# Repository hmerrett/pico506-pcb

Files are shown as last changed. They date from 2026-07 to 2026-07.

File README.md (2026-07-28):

# Pico506 hardware — rev 1.0

A dedicated PCB for the Pico506 ST-506/MFM/RLL hard drive emulator: two-layer,
138 × 74 mm, all through-hole, with real card-edge tabs so it plugs into a
period ST-506 control/data cable pair the same way an ST-225 does.

**This repository is the board only.** The emulator itself — the RP2040 firmware,
the PIO signal generation, the SD card image format, and the explanation of how
any of it works — is Kuba Szczodrzyński's
[**kuba2k2/pico506**](https://github.com/kuba2k2/pico506). Read that first; this
board is useless without it. Kuba's write-up
[*Emulating a 1987 proprietary RLL hard drive*](https://kuba.szczodrzynski.pl/posts/toshiba-t1200/rll-hdd-emulator/)
is the long-form story of the project and the reference for the interface
behaviour this layout is built around.

This file covers the board: what to buy, how to strap it, and what to tell
the fab. See [Credits](#credits) for what is original here and what is not.

> **Status:** schematic and layout are complete and clean — ERC 0, DRC 0 at
> `--severity-all` (see [`erc.txt`](erc.txt), [`drc.txt`](drc.txt)).
> **It has not been fabricated or brought up yet.** Nothing here has been
> validated against real hardware; treat rev 1.0 as a first spin.

| Front | Back |
|---|---|
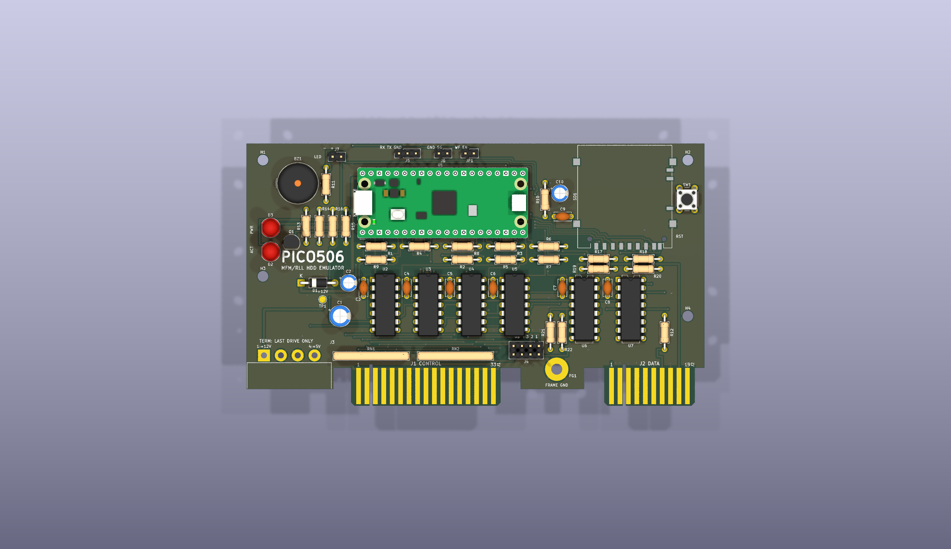
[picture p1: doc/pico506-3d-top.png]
front
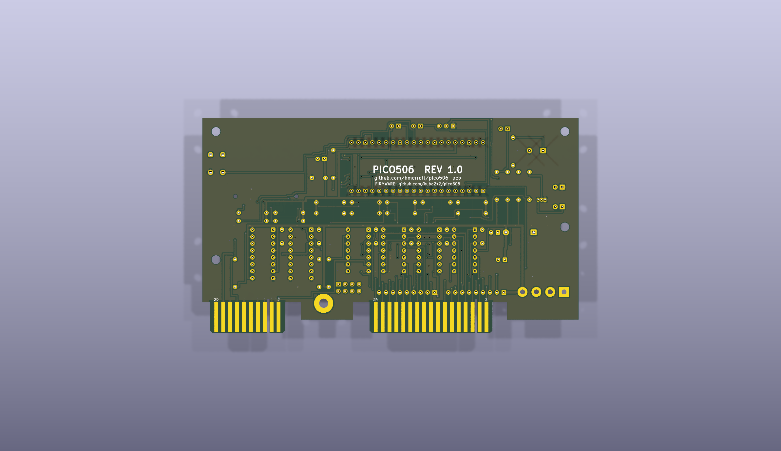
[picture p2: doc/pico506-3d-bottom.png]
back
|  |  |

Also in [`doc/`](doc/): an isometric render, front/back layer PDFs, gerbers +
Excellon (`pico506-gerbers.zip`), a CSV BOM and a placement file. The schematic
PDF is [`pico506-sch.pdf`](pico506-sch.pdf).

## Bill of materials

36 line items, 62 parts, nothing surface-mount and nothing exotic. Quantities
and designators below are generated from the schematic — the machine-readable
copy is [`doc/pico506-bom.csv`](doc/pico506-bom.csv).

### Semiconductors

| Ref | Qty | Value | Notes |
|---|---|---|---|
| U1 | 1 | Raspberry Pi Pico | Pico or Pico W, THT header or castellated. The footprint takes either. |
| U2, U3 | 2 | 74LS05 | Hex inverter, **open collector**. Not 7404 — the open-collector output is what lets the terminated 5 V bus idle high. |
| U4, U5 | 2 | 7438 | Quad NAND, **open collector**, buffered. Plain `7438` (or `74S38`) is preferred over `74LS38`: the LS part sinks 24 mA where the bus wants 40 mA to hold a 220/330-terminated line at a valid low. 74LS38 will usually work with one drive on a short cable; use 7438 if you want spec margin. |
| U6 | 1 | AM26LS31CN | Quad RS-422 differential **driver** (READ data out). |
| U7 | 1 | MC3486N | Quad RS-422 differential **receiver** (WRITE data in). **AM26LS32AC** is a drop-in alternative and is usually easier to find. |
| Q1 | 1 | 2N3904 | LED sink for the front-panel activity LED. Any small NPN. |
| D1 | 1 | 1N5817 | Schottky, feeds the Pico's VSYS from +5 V. A 1N5819 or SS14-class part is fine; don't substitute a plain 1N400x — the forward drop leaves too little VSYS headroom. |
| D2 | 1 | LED 5 mm amber | `ACT` — activity. |
| D3 | 1 | LED 5 mm green | `PWR` — power. |

### Passives

| Ref | Qty | Value | Notes |
|---|---|---|---|
| RN1 | 1 | 220 Ω SIP-9 | Terminator pull-up half. **Bourns 4609X-101-221** (bussed, 8 resistors, common pin 1). Fit in a 9-pin SIP socket — see [Termination](#termination). |
| RN2 | 1 | 330 Ω SIP-9 | Terminator pull-down half. **Bourns 4609X-101-331**. Also socketed. |
| R21 | 1 | 220 Ω | Fixed 220/330 divider on the *selected* drive-select line, after the J4 jumper — the way an ST-225 does it. Not removable. |
| R22 | 1 | 330 Ω | ” |
| R1–R9, R16 | 10 | 1 kΩ | R1–R9 pull the 74LS05 open-collector outputs up to +3V3 for the Pico. R16 is the PWR LED resistor. |
| R10, R14, R15 | 3 | 470 Ω | R10 is the WRITE FAULT input pull-up; R14/R15 are the ACT LED resistors (on-board and front-panel). |
| R11, R12 | 2 | 100 Ω | R11 buzzer series, R12 terminates the WRITE differential pair across U7's inputs. |
| R13 | 1 | 4.7 kΩ | Q1 base. |
| R17–R20 | 4 | 10 kΩ | SD card SPI pull-ups. |
| C1 | 1 | 100 µF 16 V | Bulk on +5 V. Radial, 6.3 mm body, 2.5 mm pitch. |
| C2 | 1 | 22 µF 16 V | Bulk on VSYS. Radial, 5 mm body. |
| C3–C9 | 7 | 100 nF | Ceramic disc, 5 mm pitch. One per logic IC (C3–C8) plus one for the SD socket (C9). |
| C10 | 1 | 10 µF 16 V | +3V3 bulk next to the SD socket. |

All resistors are 1/4 W axial on a 10.16 mm (0.4 in) footprint — the classic
DIN0207 body with the leads bent out, so they lie flat.

### Connectors and mechanical

| Ref | Qty | Part | Notes |
|---|---|---|---|
| J1 | — | ST-506 control, 34-pin card edge | Etched into the board. Mates a 3M 3463 / AMP 88373-3 style IDC card-edge socket. |
| J2 | — | ST-506 data, 20-pin card edge | Etched into the board. Mates 3M 3461 / AMP 88373-6. |
| J3 | 1 | **AMP/TE 350211-1** 4-pos MATE-N-LOK | Cable side is **AMP 1-480424-0** with 350550-series pins. This is the standard 4-pin drive power connector. The footprint expects the vertical header with its legs formed 90° for rear entry — exactly what Seagate did — or use a right-angle MATE-N-LOK equivalent. |
| FG1 | 1 | **AMP 61761-2** faston tab | Frame ground, 0.187 in tab, 3.3 mm hole. Or just bolt a ring lug through it. |
| SD1 | 1 | **Hirose DM1AA-SF-PEJ(82)** | Full-size push-push SD socket. The card ejects over the board's front edge. |
| SW1 | 1 | 6 mm tactile switch, 4.3 mm | `RST` — pulls the Pico's RUN low. |
| J4 | 1 | 2×4 pin header, 2.54 mm | Drive select. See [Straps](#straps-and-jumpers). |
| J5 | 1 | 1×3 pin header | UART console: GND / TX / RX. |
| J6 | 1 | 1×2 pin header | `SERVO GATE` — 3.3 V logic, JVC RLL drives only. |
| J7 | 1 | 1×2 pin header | Front-panel activity LED: pin 1 anode, pin 2 cathode. |
| JP1 | 1 | 1×2 pin header | `WF EN` — WRITE FAULT enable. |
| TP1 | 1 | test pad | +12 V, so you can confirm the rail without probing the connector. |
| H1–H4 | 4 | M3 | 3.2 mm mounting holes. |
| — | 6 | DIP socket | 4 × DIP-14, 2 × DIP-16. Optional but recommended. |
| — | 2 | SIP-9 socket | For RN1/RN2, so the terminator can come out. **Not optional** if this drive might sit mid-chain. |

## Straps and jumpers

### J4 — drive select

The silkscreen reads `DS 4 3 2 1` left to right (west to east). Each column is
one J1 drive-select line on its odd pin and the shared `DS_SEL_N` node on its
even pin; fitting a shunt across one column selects that drive address.
**Fit exactly one shunt.**

| Column | J1 pin | Selects |
|---|---|---|
| `1` (east) | 26 | DS1 |
| `2` | 28 | DS2 |
| `3` | 30 | DS3 |
| `4` (west) | 32 | DS4 |

Which one you want depends on your controller's cable. With a straight-through
control cable, the first drive is DS1. With an **IBM-style twisted control
cable** the twist reassigns the select lines between the two drive connectors,
and the drive on the end (twisted) connector wants **DS2** — that is the
intended default for this board. Check your controller's manual: this is the
single most common reason an otherwise-working drive is not detected.

Downstream of the shunt, `DS_SEL_N` carries its own fixed 220/330 divider
(R21/R22), matching ST-225 practice — that termination stays fitted regardless
of chain position.

### Other headers

| Header | Fitted | Effect |
|---|---|---|
| JP1 `WF EN` | open (default) | WRITE FAULT is not driven; the line idles inactive via R10. |
| JP1 `WF EN` | closed | Firmware drives WRITE FAULT from GP22. Only close this if your firmware build actually asserts it. |
| J6 `SERVO GATE` | — | 3.3 V SERVO GATE for JVC JD-3824-class RLL drives. Leave unconnected for ordinary MFM. |
| J7 `FRONT LED` | — | Parallels the on-board ACT LED to a panel LED. Pin 1 is the anode. |
| J5 `UART` | — | Console at GND/TX/RX. 3.3 V logic — do not connect a 5 V TTL adapter. |

## Termination

ST-506 is a daisy chain, and the spec puts a 220 Ω/330 Ω divider on every
control input — but **only on the drive at the far end of the cable.** Every
other drive on the chain must have its terminator removed, or the lines are
loaded several times over and nothing reads reliably.

That is what RN1 (220 Ω) and RN2 (330 Ω) are, and it is why they belong in
sockets:

- **Last drive on the control cable** (or the only drive): RN1 and RN2 fitted.
- **Any other position:** pull both packs out.

The silkscreen says `TERM: LAST DRIVE ONLY` next to them as a reminder. The
data cable (J2) is point-to-point and needs no such choice — the WRITE pair's
terminator (R12) is soldered down.

## Connectors and keying

Both card-edge tabs stand 5 mm proud of the main outline, are 1.6 mm thick, and
carry a **0.914 mm key slot routed 12.5 mm in from the tab tip, between pins 4
and 6** — the standard ST-506 keying, so a connector cannot be seated
backwards. Odd pins are on the front (F.Cu) face, even pins on the back, at
2.54 mm pitch; fingers are 1.40 mm wide and 11.43 mm long with the copper
pulled back 0.45 mm from the routed tip.

### Relief cut-outs

The fingers are 11.43 mm long but the tab only stands 5 mm proud, so the board
is cut away **beside** each tab as well — otherwise the mating socket's shell
hits the main board edge after 5 mm with two thirds of the finger length still
unengaged. Each relief runs inboard to y = 67.57 mm, level with the finger
tops, giving a free-standing tongue exactly as long as the gold:

| Relief | Width | Note |
|---|---|---|
| J1 west | **5.34 mm** | Limited by the J3 power housing 0.6 mm further west, not by choice — see below. |
| J1 east | 6.00 mm | |
| J2 west | 6.00 mm | |
| J2 east | 2.90 mm | The board simply ends here; the whole south-east corner is removed, so there is nothing east of the J2 tab to foul. |

The overall envelope is unchanged — 138 × 74 mm plus the 5 mm tabs — so this
costs nothing mechanically.

> **Check this against your actual sockets.** The J1 relief can only be
> 5.34 mm wide on its west side, because the J3 power connector housing (a full
> 1.00 in wide, its east face at x = 25.62 mm) is immediately beyond it. If
> your J1 socket needs more than that, the obstruction is the *power connector
> body*, not the board, and the fix is to shift J3 east — which moves it off the
> measured ST-225 position. `TAB_RELIEF_W` in
> [`tools/layout.py`](tools/layout.py) is the single knob for relief width.

Extending the tabs further instead of notching would also work and is a
one-constant change (`TAB_PROTRUDE`), but it moves every finger pad south,
invalidates all the hand-routed finger escapes, and grows the board's depth
past the drive's rear plane.

Lateral positions follow the measured ST-225 arrangement so ordinary cable
dressing just works. Measured from the board's west edge:

| Tab | Centre | Width | Pins |
|---|---|---|---|
| J1 control | 54.10 mm | 45.09 mm | 34 |
| J2 data | 121.45 mm | 27.30 mm | 20 |

J1 uses the ST-506/412 control pinout (even pins signal, odd pins ground); J2
uses the ST-412 data pinout, with the two differential pairs on 13/14 (WRITE)
and 17/18 (READ). Both are enumerated in
[`tools/netlist.py`](tools/netlist.py), which is the single source of truth for
the whole design.

J3 power is the usual 4-pin order: **pin 1 = +12 V**, pins 2 and 3 ground,
**pin 4 = +5 V**, marked on the silkscreen. +12 V is not used by the emulator —
it is brought to TP1 only so you can verify the supply.

## Mechanical

Everything below is from [`tools/layout.py`](tools/layout.py); the origin is the
board's north-west corner viewed from the component side.

- **Main outline:** 138.0 × 74.0 mm, 1.6 mm FR4. The rear (south) edge is the
  drive's rear plane; the two card-edge tabs protrude 5 mm past it for cable
  access, with 1 mm 45° corner cuts at the tab tips. The board is notched
  beside each tab so the sockets can seat — see
  [Relief cut-outs](#relief-cut-outs). The south-east corner is cut away
  entirely as part of that.
- **Mounting holes** (3.2 mm, M3): H1 (5, 5), H2 (133, 5), H3 (5, 40),
  H4 (133, 52).
- **Frame ground** faston FG1 sits between the two tabs, 6 mm in from the rear
  edge at x = 93.5.
- **SD card** ejects over the *front* (north) edge — leave that edge clear in
  any enclosure.
- **USB** and the `RST` button are the other two things you will want access
  to: USB is at the Pico's west end, `RST` at the east edge.

If you are building an enclosure or a bay adapter: this board is not a
mechanical drop-in for a 3.5 in or 5.25 in drive. It reproduces the *electrical
and connector* geometry of an ST-225 rear face, not its chassis. On a real
drive the card-edge mid-plane sits roughly 4.8 mm above the bay floor; if you
want the cables to land where a drive's would, that is the dimension to match,
and SFF-8501 gives the bay hole pattern to mount against. The four holes here
are a generic rectangle, not the SFF pattern — pick them up with standoffs.

## Fab notes

Two layers, 1.6 mm FR4, 1 oz copper, minimum track 0.2 mm and minimum
clearance 0.18 mm — comfortably inside every cheap prototype service's
capability. Two things are *not* default, though, and both matter:

1. **Card-edge fingers need hard gold.** Selective ENIG or hard gold plating on
   the tabs, Ni ≥ 2.5 µm / Au ≥ 0.4 µm. HASL fingers will wear through and
   go intermittent. This is usually a paid option — say "gold fingers".
2. **Bevel the tabs, 30°, both faces, on both card edges.** Without the bevel
   the tabs are hard to insert and will chew the connector.

Also: the key slots are 0.914 mm routed slots cut right through, so the fab
needs to treat them as internal routing, not drills — as are the four relief
notches beside the tabs. All of it is on `Edge.Cuts`; the two plating notes are
written onto the `Cmts.User` layer of the board so they travel with the gerbers.

## Assembly order

Low parts first, and leave the socketed parts until you have tested the rails:

1. Diodes, resistors, resistor packs' sockets, IC sockets.
2. Ceramics, then electrolytics (watch polarity on C1/C2/C10 and D1's band).
3. Headers, SW1, SD socket, LEDs, buzzer, Q1.
4. J3 power and the FG1 faston.
5. **Before fitting any IC:** apply drive power and check +5 V, +3V3 (Pico
   fitted), +12 V at TP1, and that nothing is warm.
6. Fit the Pico, then the logic ICs, then RN1/RN2 if this is the last drive.
7. Set the J4 shunt for your controller's cable before first use.

## Regenerating the design

The schematic and board are **generated**, not hand-drawn —
[`tools/netlist.py`](tools/netlist.py) is the single source of truth and both
generators consume it. Do not edit the `.kicad_sch` or `.kicad_pcb` by hand;
your changes will be overwritten.

```bash
cd tools
python3 gen_sch.py ../pico506.kicad_sch   # schematic (+ writes sch_uuids.json)
python3 gen_footprints.py                 # project footprint library
./check.sh                                # board + zone fill + full DRC
./export.sh                               # renders, PDFs, gerbers, BOM
```

`check.sh` regenerates the board, fills the zones, re-stamps the `.kicad_pro`
(pcbnew's save clobbers it) and runs `--severity-all` DRC into
[`drc.txt`](drc.txt). It also surfaces the generators' own warnings — a
failed ground link or an unrouted net shows up there long before you notice it
as "unconnected items" in DRC.

Two analysis helpers, both needing KiCad's bundled python
(`/Applications/KiCad/KiCad.app/Contents/Frameworks/Python.framework/Versions/Current/bin/python3`):

- **`tools/stitch.py`** — walks the GND pour, unions every ground island with
  the tracks, vias and pads that touch it, and reports any fragment the main
  plane does not reach, along with a ready-to-paste fix (stitch via, bridge
  track, or a pad-to-pad link). This is how the ground plane got from six
  orphaned fragments — including floating IC ground pins — to a single
  connected plane. **Re-run it after any routing or placement change**: the
  coordinate-based entries in `GND_STITCH_VIAS` go stale as soon as the maze
  router lands differently, and a stale via can end up sitting on a signal
  track.
- **`tools/place_check.py`** — reports courtyard boxes and how deeply
  overlapping pairs interpenetrate, so a placement nudge can be sized instead
  of guessed.

### Things that will bite you

- **Some ground pads cannot be rescued after routing.** The inter-DIP corridors
  seal once the signal router fills them, and several have no B.Cu pour beneath
  to via down to. Those rescues (`GND_STUBS` in `gen_pcb.py`) are routed *as
  first-class nets inside the router's search*, so a pass only counts if the
  signals and the ground links both fit. Moving one to a post-routing pass will
  silently strand a decoupling cap's ground.
- **`router.CLR` is 0.24 mm against a 0.18 mm rule.** The slack absorbs a
  route's closest approach between grid cells. Raising it to 0.25 leaves the
  U3/U4 corridor one track short of holding both the signals and C5's ground
  rescue; lowering it starts producing real clearance violations.
- **R10 must stay at x = 90.** The WRITE-FAULT riser threads between the +3V3
  trunk descent at x = 87.9 and R10's pad column; that gap is what fits.
- **Reference designators are placed automatically** (`place_references()` in
  `gen_pcb.py`), by trying positions around each part and taking the first that
  clears every mask aperture, all footprint silk, the board texts and the board
  edge. Don't hand-place them — adjust the candidate list instead.
- **`lib_footprint_mismatch` is set to `ignore`** in the project file. The board
  is regenerated from the libraries every build, so "the board copy has drifted
  from the library" cannot happen the way it can on a hand-edited board. KiCad
  flags U1 anyway; its pads, graphics, zones and attributes all compare
  identical, and the residual difference is bookkeeping that survives a pcbnew
  load/save round-trip. Every other rule is at its default severity.

Longer-form layout history and the routing plan are in
[`tools/ROUTING_PLAN.md`](tools/ROUTING_PLAN.md).

## Credits

The Pico506 emulator is by **Kuba Szczodrzyński** —
[kuba2k2/pico506](https://github.com/kuba2k2/pico506), described at length in
[*Emulating a 1987 proprietary RLL hard drive*](https://kuba.szczodrzynski.pl/posts/toshiba-t1200/rll-hdd-emulator/).
That project is the emulator: the firmware, the PIO signal generation, the
level-shifter/inverter circuit this board's logic section is a direct
descendant of, and the pin assignment the whole layout is wired to. Without it
there is nothing to put on a PCB.

What this repository adds is the board itself: the schematic capture, the
two-layer layout, the ST-506 card-edge tabs and their ST-225-derived geometry,
the project footprint library, and the Python generators in
[`tools/`](tools/) that produce all of it. Bugs in the board are mine, not
upstream's.

Also drawn on: the [ST-506/ST-412 interface](https://en.wikipedia.org/wiki/ST-506/ST-412)
pinouts and the 220/330 termination and drive-select conventions from Seagate's
ST-225 documentation, and the [HDD Clicker](https://www.vogons.org/viewtopic.php?t=90047)
for the buzzer idea that upstream implements.

## Licence

[GNU General Public License v3.0](LICENSE) — the same licence as upstream, so
the board and the firmware it exists to carry stay under the same terms.

Copyright © 2026 Henry Merrett (this PCB: schematic, layout, footprints and
generators).
Copyright © 2025 Kuba Szczodrzyński (Pico506, from which this board's circuit
is derived).

This is a hardware design under a software licence, which is how upstream is
licensed and therefore what a derivative here has to be. In practice: the
design files are the "source", and if you fabricate, modify or distribute the
board you owe the recipients those files under the GPL. There is no warranty,
and note that **rev 1.0 has never been fabricated** — see the status note at
the top.

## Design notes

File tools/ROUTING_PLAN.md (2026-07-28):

# Pico506 PCB — routing plan (handoff notes)

## STATUS after task 11 — CARD-EDGE RELIEF CUT-OUTS

The tabs stood only TAB_PROTRUDE (5 mm) proud of a full-width rear edge, but
the fingers are FINGER_LEN (11.43 mm) long — so a mating socket's shell hit the
board edge with two thirds of the gold unengaged. The board is now cut away
beside each tab, inboard to `L.tab_relief_y()` = 67.57 (level with the finger
tops), leaving each tab a free-standing tongue the full 11.43 mm long. Envelope
unchanged; no pad moved. `TAB_RELIEF_W` (6.0) is the knob.

Consequences handled:

- **J1's GND rail had to change.** Every odd J1 finger is GND and the rail at
  y67.95 used to reach x29.6/x78.4 to meet the pour outside the tab keepout —
  both of which are now cut away. Each half now jogs north to y = ry-0.6 first,
  onto the full-width board, and runs out to the pour from there.
- **The reference placer needed to learn about cut-outs.** It only bounded refs
  by the board rectangle, so it put J3's ref inside the new notch. `CUTOUTS`
  (relief notches + the inboard part of each key slot) is now a hard no.
- J1's **west** relief is clamped to 5.34 mm, not 6.0: the J3 power housing's
  east face is at x25.62 and `L.tab_relief_x()` keeps `J3_RELIEF_GAP` off it.
  If a real socket needs more, the obstruction is the power connector body and
  J3 has to move east, off the measured ST-225 position.
- J2's **east** relief is 2.90 mm because the board ends at x138 — the whole
  south-east corner is simply removed, so nothing is east of that tab at all.

DRC 0, ERC 0, GND still one connected plane after the change.

## STATUS after task 10 — DRC CLEAN, ARTEFACTS EXPORTED

ERC 0, DRC 0 at `--severity-all`. GND is one connected plane (63 fill
islands, no orphans). Board not yet fabricated.

What task 10 actually changed — see [../README.md](../README.md) for the
user-facing write-up and the "things that will bite you" list:

- **6 unconnected items were real defects, not cosmetics.** U4.7, C5.2, C3.2,
  U3.13, SD1.3/SD1.6 and three Pico ground pins were sitting in pour fragments
  that reached nothing. `tools/stitch.py` (new) finds these: it unions every
  GND island with the copper touching it and reports orphans plus a fix.
- Rescues that cannot be fitted after routing now route **inside** the maze
  router's search as first-class nets (`GND_STUBS` in gen_pcb.py) — the
  inter-DIP corridors seal once signals fill them and several have no B.Cu pour
  underneath to via to. A pass only counts if signals *and* ground links fit.
- `router.CLR` 0.25 -> 0.24. At 0.25 the U3/U4 corridor is one track short of
  holding both the signals and C5's rescue.
- Custom pad shapes are now measured from their primitives, not `(size)`; the
  Pico's castellated pads reach 1.13 mm, not 0.8, and the router was routing
  into them.
- Reference designators are auto-placed (`place_references()`), which is what
  cleared ~100 silk violations. Board texts moved off copper; the B.SilkS
  branding now sits between the Pico's two pin rows.
- Real body collisions fixed by placement: Q1 vs D2/D3 overlapped by ~0.85 mm.
  Also nudged C2/C3/C9/C10/D1/BZ1/R11/R21/R22/C7. `tools/place_check.py` (new)
  sizes these instead of guessing.
- J3's silk outline no longer runs off the board edge or across its own pads;
  the SD socket's courtyard was pulled in to the body.
- `lib_footprint_mismatch` set to `ignore` (the board is regenerated from the
  libraries every build, so library drift is structurally impossible here).
- `tools/export.sh` (new) produces renders, schematic PDF, layer PDFs, gerbers,
  drill, BOM and placement into `hardware/doc/`.

**Re-run `tools/stitch.py` after any routing or placement change.** The
coordinate-based `GND_STITCH_VIAS` go stale as soon as the router lands
differently, and a stale via can end up on a signal track.

## STATUS after task 9 — BOARD FULLY ROUTED

Every net is connected: zero shorts, crossings, clearance or hole errors.
Remaining DRC (task 10): 6 unconnected items that are all GND plane-split
pairs (pour fragments each carrying ground but no copper bridge between
them — needs a few stitch vias placed after visual inspection of the fills),
60 silk_overlap + 42 silk_over_copper + 1 silk_edge (text/ref cleanup),
15 courtyards_overlap (mostly ref-text/courtyard cosmetics to review),
1 lib_footprint_mismatch (Pico footprint intentionally differs: harmless).

Task 9 was done with tools/router.py — a net-aware two-layer grid maze
router (0.3175 mm grid, 0.3 mm tracks, 0.6/0.3 vias) run inside
gen_pcb.routes_gpio_auto() with retry/rip-up and randomized restarts;
chronically congested nets got verified hand routes in routes_gpio_hand()
(HS0/HS1/HS2 GPIO drops+links, SELECTED tree incl. R13 leg at y25.4 under
the module, WR_DATA, SD corner joins). The select-monitor inverter moved
from U3 gate 3 (pins 5/6, now spare/NC) to U5's spare NAND gate (pins
12+13 tied = DS_SEL_N in, pin 11 = SELECTED out) — netlist + schematic
updated and ERC re-verified. ~14 GND relief stubs+vias feed THT ground
pads the pours can no longer reach through the routing maze.

check.sh regenerates everything (sch UUIDs assumed current), refills
zones, re-stamps the .kicad_pro (pcbnew's save clobbers it — note the
netclass needs its "priority" field or KiCad ignores the 0.18 clearance)
and runs full-severity DRC into hardware/drc.txt.

## STATUS after tasks 6+7 (power + termination bus routed)

DRC: ZERO copper errors. Remaining: 70 unconnected (tasks 8/9 nets), plus
silk/courtyard warnings (task 10). Regen + check: `tools/check.sh`.

Key learnings that supersede sections below:
- Layer discipline that WORKS: ALL band horizontals on F.Cu in 0.75 mm slots
  y = 57.5, 58.25, 59.0, 59.75, 60.5, 61.25, 62.0; ALL verticals on B.Cu.
  B verticals never cross F horizontals — the only real constraints are
  via spacing: via(0.6/0.3) to parallel track ≥0.75 center-lateral, via-via
  ≥0.85, via-to-DIP-hole ≥~1.0 radial. Slot assignment is nearly free.
- J1 escapes: B verticals from finger pads (y68.5) north across the RN row;
  RN1@(27.43,64)/RN2@(52.83,64) pads sit on the half-grid so every escape
  passes with 1.27 mm to each side. Escape x = finger x (2.54 grid at
  33.78 + 2.54k).
- Slot usage (net@slot): WG/DS1@57.5, STEP/DS2@58.25, DIR@59.0, HS0/DS3@59.75,
  HS1/DS4@60.5, HS2@61.25, HS3@62.0. DS vias at x 64.26..71.88 (DS1's at
  64.9); J4 at (88.12,61) rot 270 => columns DS4..DS1 west->east at
  80.5/83.04/85.58/88.12 (odd row y61, DS_SEL row y63.54).
- RN2 line pins were REMAPPED in netlist.py (2:WG 3:STEP 4:HS3 5:DIR 6:HS0
  7:HS1 8:HS2) so HS3's U3.9 entry vertical (x60.0) shares the RN2.4 stub
  column same-net. RN1 stays in natural order.
- U3 gates swapped in netlist: 3/4 = select-monitor (WG_GATED), 9/8 = HS3.
- Occupied B verticals in the band (do not collide in tasks 8/9):
  escapes at all 17 finger x's up to their slot; SIP stubs at RN1
  29.97..45.21 and RN2 55.37..70.61 (slot..64); entry verts x 36.6, 39.7,
  40.6, 42.15(+jog to 42.67), 42.95, 47.0, 60.0(+jog to 60.45); DS_SEL B at
  x49.6 (46.08..58.0), jog y58.0 x49.6..53.2, x51.56 (58..65.5),
  x53.2 (56.55..58).
- DS_SEL_N is an all-F tree: main y65.5 from x51.56 to (80.5,63.54) bus
  through J4 evens to 88.12; east legs y63.9 / y60.3 / lane y49.89 to
  R21.2 (91,51.84), R22.1 (94.5,62), U6.12; vias at (51.56,65.5),
  (53.2,56.55).
- FG1 moved to (93.5, 68).

## STATUS after task 8 — outputs + data pairs routed, ZERO copper errors

Remaining 56 unconnected = task 9 nets only (GPIO, pull-up pin2s, SD, UART,
RUN, buzzer, LED chain, SERVO_GATE header, +2 GND pads to check).

New occupied resources (add to the task-7 list):
- B lanes: y42.27 (SKC, x41.4-73), y44.81 (TRK0, 43.94-70.3, jogs to y43.98
  around x47-49.6 and x60-62.6), y47.35 (INDEX, 56.64-62.65), y49.89 (RD_M,
  99.6-108.6 and 127.0-130.34), y52.43 (DRV, 78.6-89.5), y60.3 (WR_P,
  122.05-124.6), y64.0+65.9 (DRV, 89.5-110.02), y65.2 (WR_M jog), y11.9
  (WF_IN, 69.29-88.6); B verts x69.29(4.6-11.9), x88.6(11.9-22),
  x90(22-26.2), x70.3, x73.0, x62.65, x62.75(53.7-57.5), x75.5(46.08-62.75),
  x78.6, x89.5, x97.7, x99.6(46.08-49.89), x122.05(42.27-60.3),
  x124.6(60.3-62), x126(44.81-51.84), x127.4(51.84-65.2),
  x130.34(49.89-68.5).
- F lanes: y36.3 (RD_P, 99.6-130.34), y42.27 (WR_P, 112-122.05), y44.81
  (WR_M, 113.35-126), y47.35 (WR_RX, 49.75-113.5), y49.89 (RD_M hop,
  108.6-127.0), y57.5 (READY, 59.18-62.75), y62.75 (WF, 46.48-75.5),
  y39.75 (WF_IN, 78.3-90) + F verts x49.75, x113.5, x113.35, x123.85,
  x130.34(36.3-68.5), x90(26.2-39.75).
- J2 grounds are now per-column stub+via at y66.05 (pin 2's via offset to
  x111.3); no rails. Stitch vias moved: (85,18), (103,62).
- HS1's U2.11 entry is B-vert + via pair at x42.95 with an F entry at
  y48.62 (B entry would cross the TRK0 escape).

## Task 9 leftovers/reminders
- RUN lane planned y13.4 B (WF_IN sits at y11.9; keep 0.65 apart).
- GPIO drops: jog level y28.5 F, corridors x84.6/x86.4 east of module.
- 2 GND unconnected items to inspect (likely Q1.1/D3.1 zone spokes).

## Original notes for task 8 (superseded, kept for reference)
- Outputs' J1 fingers: SKC 41.4, TK0 43.94, WF 46.48, INDEX 56.64,
  READY 59.18. Their B escapes can run north PAST the band (B verticals
  cross F slots freely) and past the DIP pad rows using the between-rows
  B lanes at y = 42.27, 44.81, 47.35, 49.89(used west of x91 by DS_SEL —
  that piece is F so B is still free), 52.43, 54.97 (rows at 41+2.54k,
  pad edge gaps 0.94 -> lane centered, 0.27 clearance). Enter U4/U5 pins
  via col-gap verticals like task 7 did.
- CONSTRAINT: WF escape (46.48) may not pass y53.7..59.75 next to HS0's
  entry vert at x47.0 (lateral 0.52). Either put WF's turn NORTH of y53.4
  (lane 52.43 or above), or dogleg WF's escape east to x48.3 above y67
  (48.3 is free below y41 only up to the C4 stub — the vertical must end
  south of y41; C4 stub occupies 48.3 x at y39.5..41).
- READY escape (59.18) cannot pass the U3 col2 pad column (58.62,
  y41..56.24) — clearance 0.04. Turn READY east/west in the band slots
  region or south of y57.04. Its target U4.5/U4.6 area is east anyway.
- U4/U5 pin nets: U4: 1 INDEX, 2 SELECTED, 3 INDEX_N(out), 4 READY,
  5 SELECTED, 6 READY_N, 9 TRK0, 10 SELECTED, 8 TRK0_N, 12 SKC,
  13 SELECTED, 11 SKC_N. U5: 1 WF_IN, 2 SELECTED, 3 WFAULT_N,
  4+5 SELECTED, 6 DRV_SELD_N (-> J2 pin 1 at x110.02, F.Cu odd side!).
- J2 write pair: 13 (+WR, F.Cu x125.26!) and 14 (-WR, B.Cu x125.26) —
  note odd pins are F, even are B, SAME column x = 110.02+2.54k for pins
  (2k+1, 2k+2). R12 at (126, 51.84..62). U7.1 (112,41) WR_DATA_P,
  U7.2 (112,43.54) WR_DATA_M, U7.3 (112,46.08) WR_RX -> U3.1 (51,41).
  Read pair: U6.2 (98,43.54) -> J2-17 (F, x130.34), U6.3 (98,46.08) ->
  J2-18 (B, x130.34).

State: schematic ERC-clean (0 violations, `--severity-all`). Board generated,
placement v3 verified by render: all 62 footprints, outline with keyed
card-edge tabs, GND zones both layers, 0 tracks routed yet.

Regenerate everything:
```
cd hardware/tools
python3 gen_sch.py ../pico506.kicad_sch      # + writes sch_uuids.json
python3 gen_footprints.py                     # -> ../pico506-lib.pretty/
python3 gen_pcb.py                            # -> ../pico506.kicad_pcb
<KiCad python> refill.py ../pico506.kicad_pcb # fill zones + validate
```
KiCad python: /Applications/KiCad/KiCad.app/Contents/Frameworks/Python.framework/Versions/Current/bin/python3
kicad-cli:    /Applications/KiCad/KiCad.app/Contents/MacOS/kicad-cli

Routes go in `build_routes()` in gen_pcb.py using `P(ref,pad)`, `route()`,
`wire_pads()`, `seg()`, `via()`. All coords are board-local (x 0..138 E,
y 0..74 S; rear/connector edge = y74). Pad coords: dict PADS after build().

## Layer discipline
- B.Cu: rear horizontal band slots y≈57.5..67.3 (0.65 pitch), the +5V spine
  at y=39.5 (0.8 mm), west power drops, LED chain y=19.84, +3V3 trunk y=29.45
  (0.6 mm).
- F.Cu: verticals north of the band zone, Pico escapes, jogs at y=28.5.
- THT pads double as layer changes (no via needed). GND: zones only.

## Key coordinates (board-local)
- J1 even-finger columns x = 33.78 + 2.54k: HS3/RWC 33.78, HS2 36.32,
  WG 38.86, SKC 41.4, TK0 43.94, WF 46.48, HS0 49.02, (16) 51.56, HS1 54.1,
  INDEX 56.64, READY 59.18, STEP 61.72, DS1 64.26, DS2 66.8, DS3 69.34,
  DS4 71.88, DIR 74.42. Finger pads span y 67.57..74.55 (B.Cu only!).
- J2 even cols x = 110.02 + 2.54k (2..20): 13 +WR = x-col? J2 signal pins:
  1 (F.Cu odd!) DSELD 110.02; 13/+WR 123.25? -> compute: even p col
  k=(p-2)/2 at 110.02+2.54k: 14 -WR 125.26, 18 -RD 130.34; odd pins 13
  (+WR) and 17 (+RD) are F.Cu at same columns as 14/18 minus… NOTE: odd
  pins are F.Cu at the SAME x as their even partner k=(p-1)/2:
  13 -> x=125.26 F.Cu, 17 -> x=130.34 F.Cu. Pin 1 -> x=110.02 F.Cu.
- RN1 pads (33.5+2.54(k-1), 64): pin1 +5V, pins2-8 = WG,STEP,DIR,HS0,HS1,
  HS2,HS3. RN2 identical at x 56.5+..., pin1 GND.
- DIP pads: U at (X,41): col1 pins 1..7 y=41+2.54(n-1) at x=X; col2 pins
  (14..8 top->bottom for DIP14; 16..9 for DIP16) at x=X+7.62.
- Pico U1 at (35,26.78) rot 90: south row y26.78 = pins 1..20 at
  x=35+2.54(k-1); north row y9.0 = pins 40..21 at x=35..83.26 (pin40 x35,
  pin21 x83.26). GP2 42.62, GP3 45.16, GP4 47.7, GP5 50.24, GP6 55.32,
  GP7 57.86, GP8 60.4, GP9 62.94, GP10 68.02, GP11 70.56, GP12 73.1,
  GP13 75.64, GP14 80.72, GP15 83.26 (all south row y26.78);
  north row y9: GP16 83.26, GP17 80.72, GP18 75.64, GP19 73.1, GP20 70.56,
  GP21 68.02, GP22 62.94, RUN 60.4, 3V3 45.16, VSYS 37.54.
- Pull-up signal ends (pin2): R1 44.16/31 ->GP2; R9 44.16/35 ->GP3;
  R4 47/31 ->GP4; R8 70.16/31 ->GP11; R2 70.16/35 ->GP12; R3 83.16/31
  ->GP13; R5 83.16/35 ->GP14; R6 86/31 ->GP16(N); R7 86/35 ->GP17(N).
  3V3 ends at x34 (R1,R9), 57.16 (R4), 60 (R8,R2), 73 (R3,R5), 96.16 (R6,R7).
- F corridors for GPIO drops: jogs at y=28.5; north-row access via x=84.6
  and x=86.4 (east of module, west of SW1).
- +5V pin pads: U2/U3/U4/U5 pin14 = (X+7.62, 41); U6/U7 pin16 = same.
  Stub down from B spine y39.5. RN1.1 (33.5,64) via B vertical x33.5
  (passes between C3 pads, edges 31.2/34.8). R21.1 (92.5,62->51.84?):
  R21 rot90 pads (92.5,62)+(92.5,51.84); pin1(=+5V)=(92.5,62).
  Corridor x92.5 crosses J4? J4 pads x82..89.62 — clear.
- Term bus (J1->RN1->RN2->U2/U3 in): B band slots; RN pads = layer change;
  from RN2 pin go north on F to the LS05 input pad.
- Diff pair: J2 13(F)/14(B) -> R12 (126, 51.84..62) -> U7 pins 1 (112,41)
  /2 (112,43.54) — swapped wiring is IN THE NETLIST already (U7.1=WR_DATA_P).
  Keep +/− runs paired, similar length; they're short (~15 mm).
  RD: U6.2 (98,43.54)=1Y ->J2-17 (130.34 F), U6.3 (98,46.08)=1Z ->J2-18
  (130.34 B col? no: -RD even pin 18 x=130.34 B). ~32 mm run; keep paired
  gap ~0.6.
- U6 ~G (pin 12) = DS_SEL_N — also to RN?? no: DS_SEL_N nodes: J4 evens
  (82..89.62 y63.54), R21.2 (92.5,51.84), R22.1 (95,62), U3 pins 5,9,11
  and U6.12. Bus it along y≈60 B slot between J4 and U3/U6.
- DS1..4: J1 cols 64.26..71.88 -> J4 odd pads (82,61),(84.54,61),(87.08,61),
  (89.62,61): B slots eastward, short.
- WF: JP1.1 (66,3)=GP22? NO: JP1.1 = WF net = GP22 (62.94, 9 north row);
  JP1.2 = WF_IN -> R10 (90, 22..11.84) + U5.1 (74,41). Route WF: GP22
  (62.94,9)->(F north zone)->JP1 pin1 (66,3). WF_IN: JP1.2 (63.46,3) ->
  east/south to R10 top (90,11.84) then U5.1 (74,41): use F verticals +
  B horizontal at y≈20?
- SD: SPI from north row GP18/19/20/21 (75.64/73.1/70.56/68.02, y9) east to
  SD pads 5,2,7,1 at y30.95 (CLK 116.5? pads: gx=114-px: p5 117.93,
  p2 110.43, p7 122.85, p1 107.93, p8 124.55, p9 105.43, p3 112.93 GND,
  p4 115.43 3V3, p6 120.43 GND). Route around module east end (x84.6/86.4
  corridors busy) — better via B: drop to B at y~11..14 and run east under
  SW1/R10 area, then F stubs. R17-20 pin2 (111.16, 34.8/37.8 rows) join.
- Buzzer: GP15 (83.26, 26.78 south row) -> R11 (24,18)!! R11 is far west:
  B horizontal y19.84 zone? BUZZ_DRV: R11.2 (24,7.84) -> BZ1.1 (14,12)+7.6?
  BZ1 pads: TDK PS1240: (14,12)±(2.5,0)? check PADS. Also LED nets west:
  SELECTED spur to R13.2, Q1 pads (10/12.54/15.08, 30), LED_SINK to D2.1
  (6,32) & J7.2 (23.46,4), LED1_A D2.2 (8.54,32)<-R14.2 (22,19.84),
  LEDX_A R15.2 (30,19.84)->J7.1 (26,4), PWR: R16.2 (26,19.84)->D3.2 (8.54,26),
  D3.1 GND zone.
- UART: GP0 (35,26.78), GP1 (37.54,26.78) -> J5 pins 2/3 at (43.46,3)/(40.92,3):
  F verticals west of module? x<35 region + jog — or B. RUN: SW1.1/2 pads
  (both ends 6mm switch) -> Pico RUN (60.4,9): F via x86.4? SW1 at (91,5):
  pads (88.6,5)+(93.4,5)? check PADS; RUN net = whichever pair per SW_PUSH
  symbol (1/2). B route y~7 under? x 86..60 at y9.8 F is close to north row
  pads — use B y≈5 then via.
- TP1 +12V: J3.1 (5.3,63.84) -> TP1 (23,47): F vertical x5.3?? J3 area free;
  route B (5.3,63.84)->(5.3,49)->(23,49)->(23,47)? watch C1 (27,52) clear.
  0.5 mm width fine.

## DRC loop
kicad-cli pcb drc --severity-all --format report -o drc.txt pico506.kicad_pcb
(refill zones first via refill.py, else zone-connection items are stale).
Expect to iterate: unconnected-items list = worklist.

## Remaining fine-placement nits seen in render v3
- R13/R14/R16/R15 sit close to Pico west end — verify courtyards in DRC.
- J4 silk "1 2 3 4" position vs header; TERM text now west (17,61.5).
- J3 pin-label silk may clip west edge (cosmetic).

## After DRC-clean
- Re-render top/bottom, export schematic PDF.
- Write hardware/README.md: BOM (with 7438-vs-74LS38 note, MC3486/AM26LS32A
  alternates, Bourns 4609X-101-221/331 SIPs, Hirose DM1AA-SF-PEJ(82),
  AMP 350211-1 + 1-480424-0 mate, AMP 61761-2 faston), jumper settings
  (DS2 default for IBM twisted cable), terminator rule, fab notes (hard
  gold + 30deg bevel, 1.6mm), case-design dimensions (board 138x74+5mm tabs,
  edge-connector positions match ST-225 lateral layout, PCB rear edge =
  drive rear plane, card-edge mid-plane ~4.8mm above bay floor on real
  drives, SFF-8501 / Seagate bay hole positions), firmware GPIO map table.

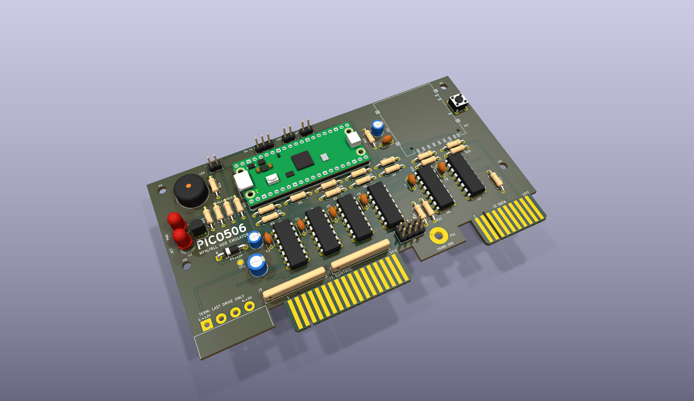
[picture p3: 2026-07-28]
doc/pico506-3d-iso.png

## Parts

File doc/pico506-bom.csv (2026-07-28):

Refs | Value | Footprint | Qty | Datasheet
BZ1 | PS1240 | Buzzer_Beeper:Buzzer_TDK_PS1240P02BT_D12.2mm_H6.5mm | 1
C1 | 100u/16V | Capacitor_THT:CP_Radial_D6.3mm_P2.50mm | 1
C2 | 22u/16V | Capacitor_THT:CP_Radial_D5.0mm_P2.50mm | 1
C3-C9 | 100n | Capacitor_THT:C_Disc_D5.0mm_W2.5mm_P5.00mm | 7
C10 | 10u/16V | Capacitor_THT:CP_Radial_D5.0mm_P2.50mm | 1
D1 | 1N5817 | Diode_THT:D_DO-41_SOD81_P10.16mm_Horizontal | 1
D2 | ACT amber | LED_THT:LED_D5.0mm | 1
D3 | PWR green | LED_THT:LED_D5.0mm | 1
FG1 | FRAME GND | pico506-lib:Faston_Tab_AMP61761 | 1
H1-H4 | M3 | MountingHole:MountingHole_3.2mm_M3 | 4
J1 | ST-506 CONTROL | pico506-lib:EdgeConn_ST506_J1_34 | 1
J2 | ST-506 DATA | pico506-lib:EdgeConn_ST506_J2_20 | 1
J3 | AMP 350211-1 | pico506-lib:PWR_MATE-N-LOK_350211_Horizontal | 1
J4 | DRIVE SELECT | Connector_PinHeader_2.54mm:PinHeader_2x04_P2.54mm_Vertical | 1
J5 | UART | Connector_PinHeader_2.54mm:PinHeader_1x03_P2.54mm_Vertical | 1
J6 | SERVO GATE 3V3 | Connector_PinHeader_2.54mm:PinHeader_1x02_P2.54mm_Vertical | 1
J7 | FRONT LED | Connector_PinHeader_2.54mm:PinHeader_1x02_P2.54mm_Vertical | 1
JP1 | WF EN | Connector_PinHeader_2.54mm:PinHeader_1x02_P2.54mm_Vertical | 1
Q1 | 2N3904 | Package_TO_SOT_THT:TO-92_Inline | 1
R1-R9,R16 | 1k | Resistor_THT:R_Axial_DIN0207_L6.3mm_D2.5mm_P10.16mm_Horizontal | 10
R10,R14,R15 | 470 | Resistor_THT:R_Axial_DIN0207_L6.3mm_D2.5mm_P10.16mm_Horizontal | 3
R11,R12 | 100 | Resistor_THT:R_Axial_DIN0207_L6.3mm_D2.5mm_P10.16mm_Horizontal | 2
R13 | 4.7k | Resistor_THT:R_Axial_DIN0207_L6.3mm_D2.5mm_P10.16mm_Horizontal | 1
R17-R20 | 10k | Resistor_THT:R_Axial_DIN0207_L6.3mm_D2.5mm_P10.16mm_Horizontal | 4
R21 | 220 | Resistor_THT:R_Axial_DIN0207_L6.3mm_D2.5mm_P10.16mm_Horizontal | 1
R22 | 330 | Resistor_THT:R_Axial_DIN0207_L6.3mm_D2.5mm_P10.16mm_Horizontal | 1
RN1 | 220 | Resistor_THT:R_Array_SIP9 | 1
RN2 | 330 | Resistor_THT:R_Array_SIP9 | 1
SD1 | SD socket | pico506-lib:SD_Hirose_DM1AA_SF_PEJ82 | 1
SW1 | RESET | Button_Switch_THT:SW_PUSH_6mm_H4.3mm | 1
TP1 | +12V | TestPoint:TestPoint_Pad_D2.0mm | 1
U1 | Raspberry Pi Pico | pico506-lib:RaspberryPi_Pico_Common_THT | 1
U2,U3 | 74LS05 | Package_DIP:DIP-14_W7.62mm | 2
U4,U5 | 7438 | Package_DIP:DIP-14_W7.62mm | 2
U6 | AM26LS31CN | Package_DIP:DIP-16_W7.62mm | 1
U7 | MC3486N | Package_DIP:DIP-16_W7.62mm | 1

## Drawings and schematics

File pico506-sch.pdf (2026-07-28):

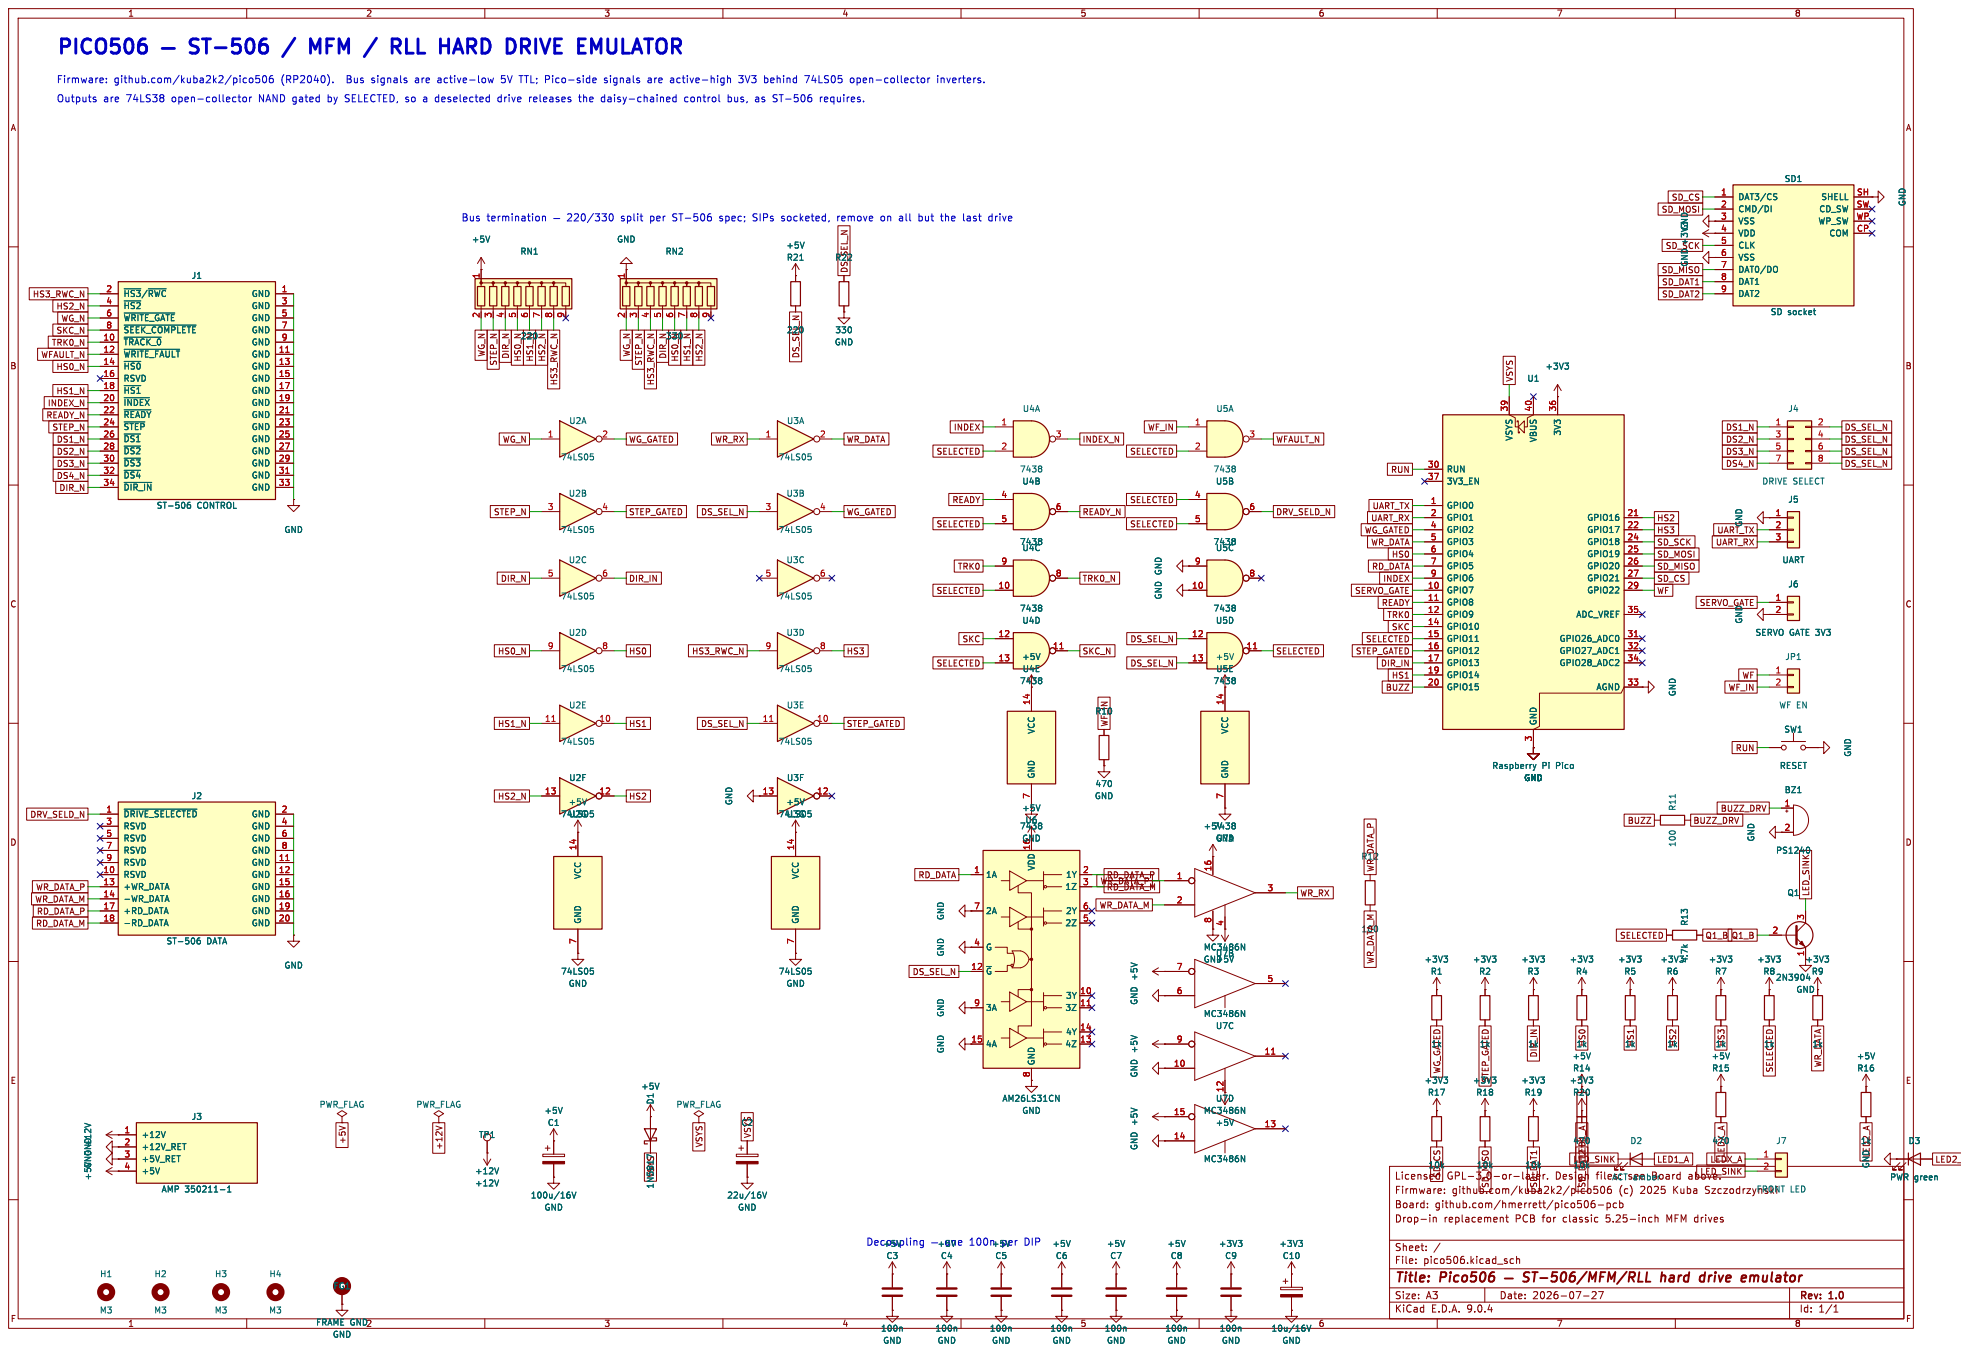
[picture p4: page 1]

3 3V3 36 GPIO16 21 GPIO17 22 GPIO18 24 GPIO19 25 GPIO20 26 GPIO21 27 GPIO22 29 ADC_VREF 35 GPIO26_ADC0 31 GPIO27_ADC1 32 GPIO28_ADC2 34 AGND 33 U1 Raspberry Pi Pico

J4 DRIVE SELECT VCC 14 GND

+3V3 GND GND GND GND

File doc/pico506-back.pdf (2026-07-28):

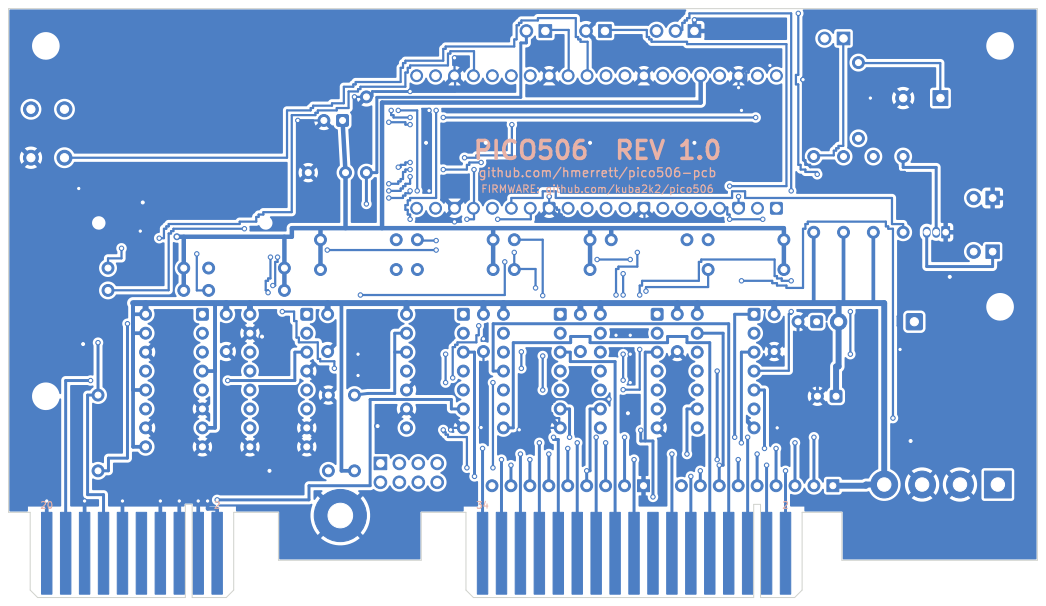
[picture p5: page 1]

FIRMWARE: github.com/kuba2k2/pico506 github.com/hmerrett/pico506-pcb

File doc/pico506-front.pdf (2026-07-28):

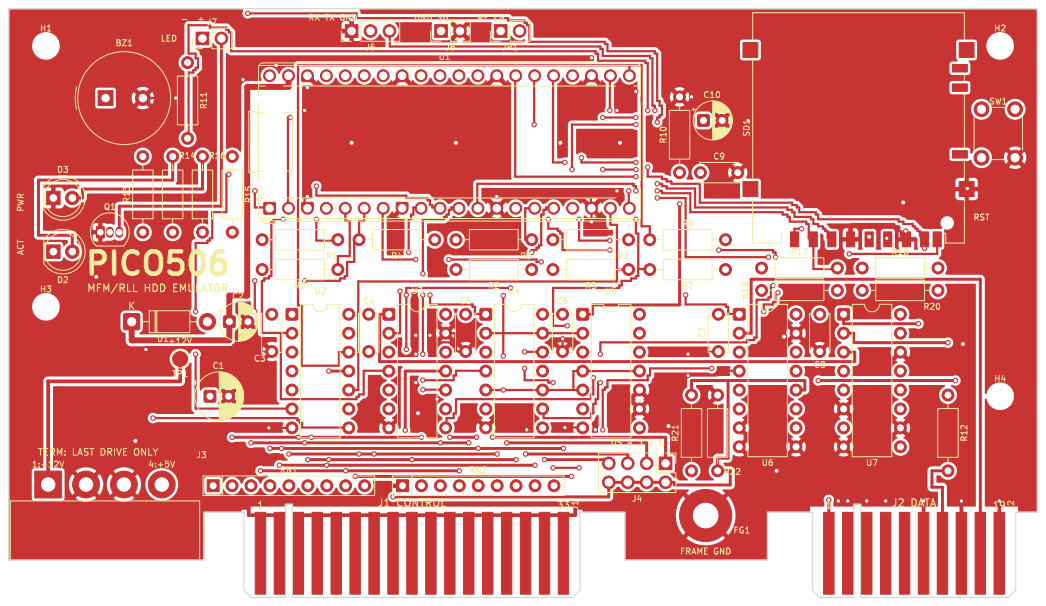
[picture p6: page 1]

TERM: LAST DRIVE ONLY MFM/RLL HDD EMULATOR

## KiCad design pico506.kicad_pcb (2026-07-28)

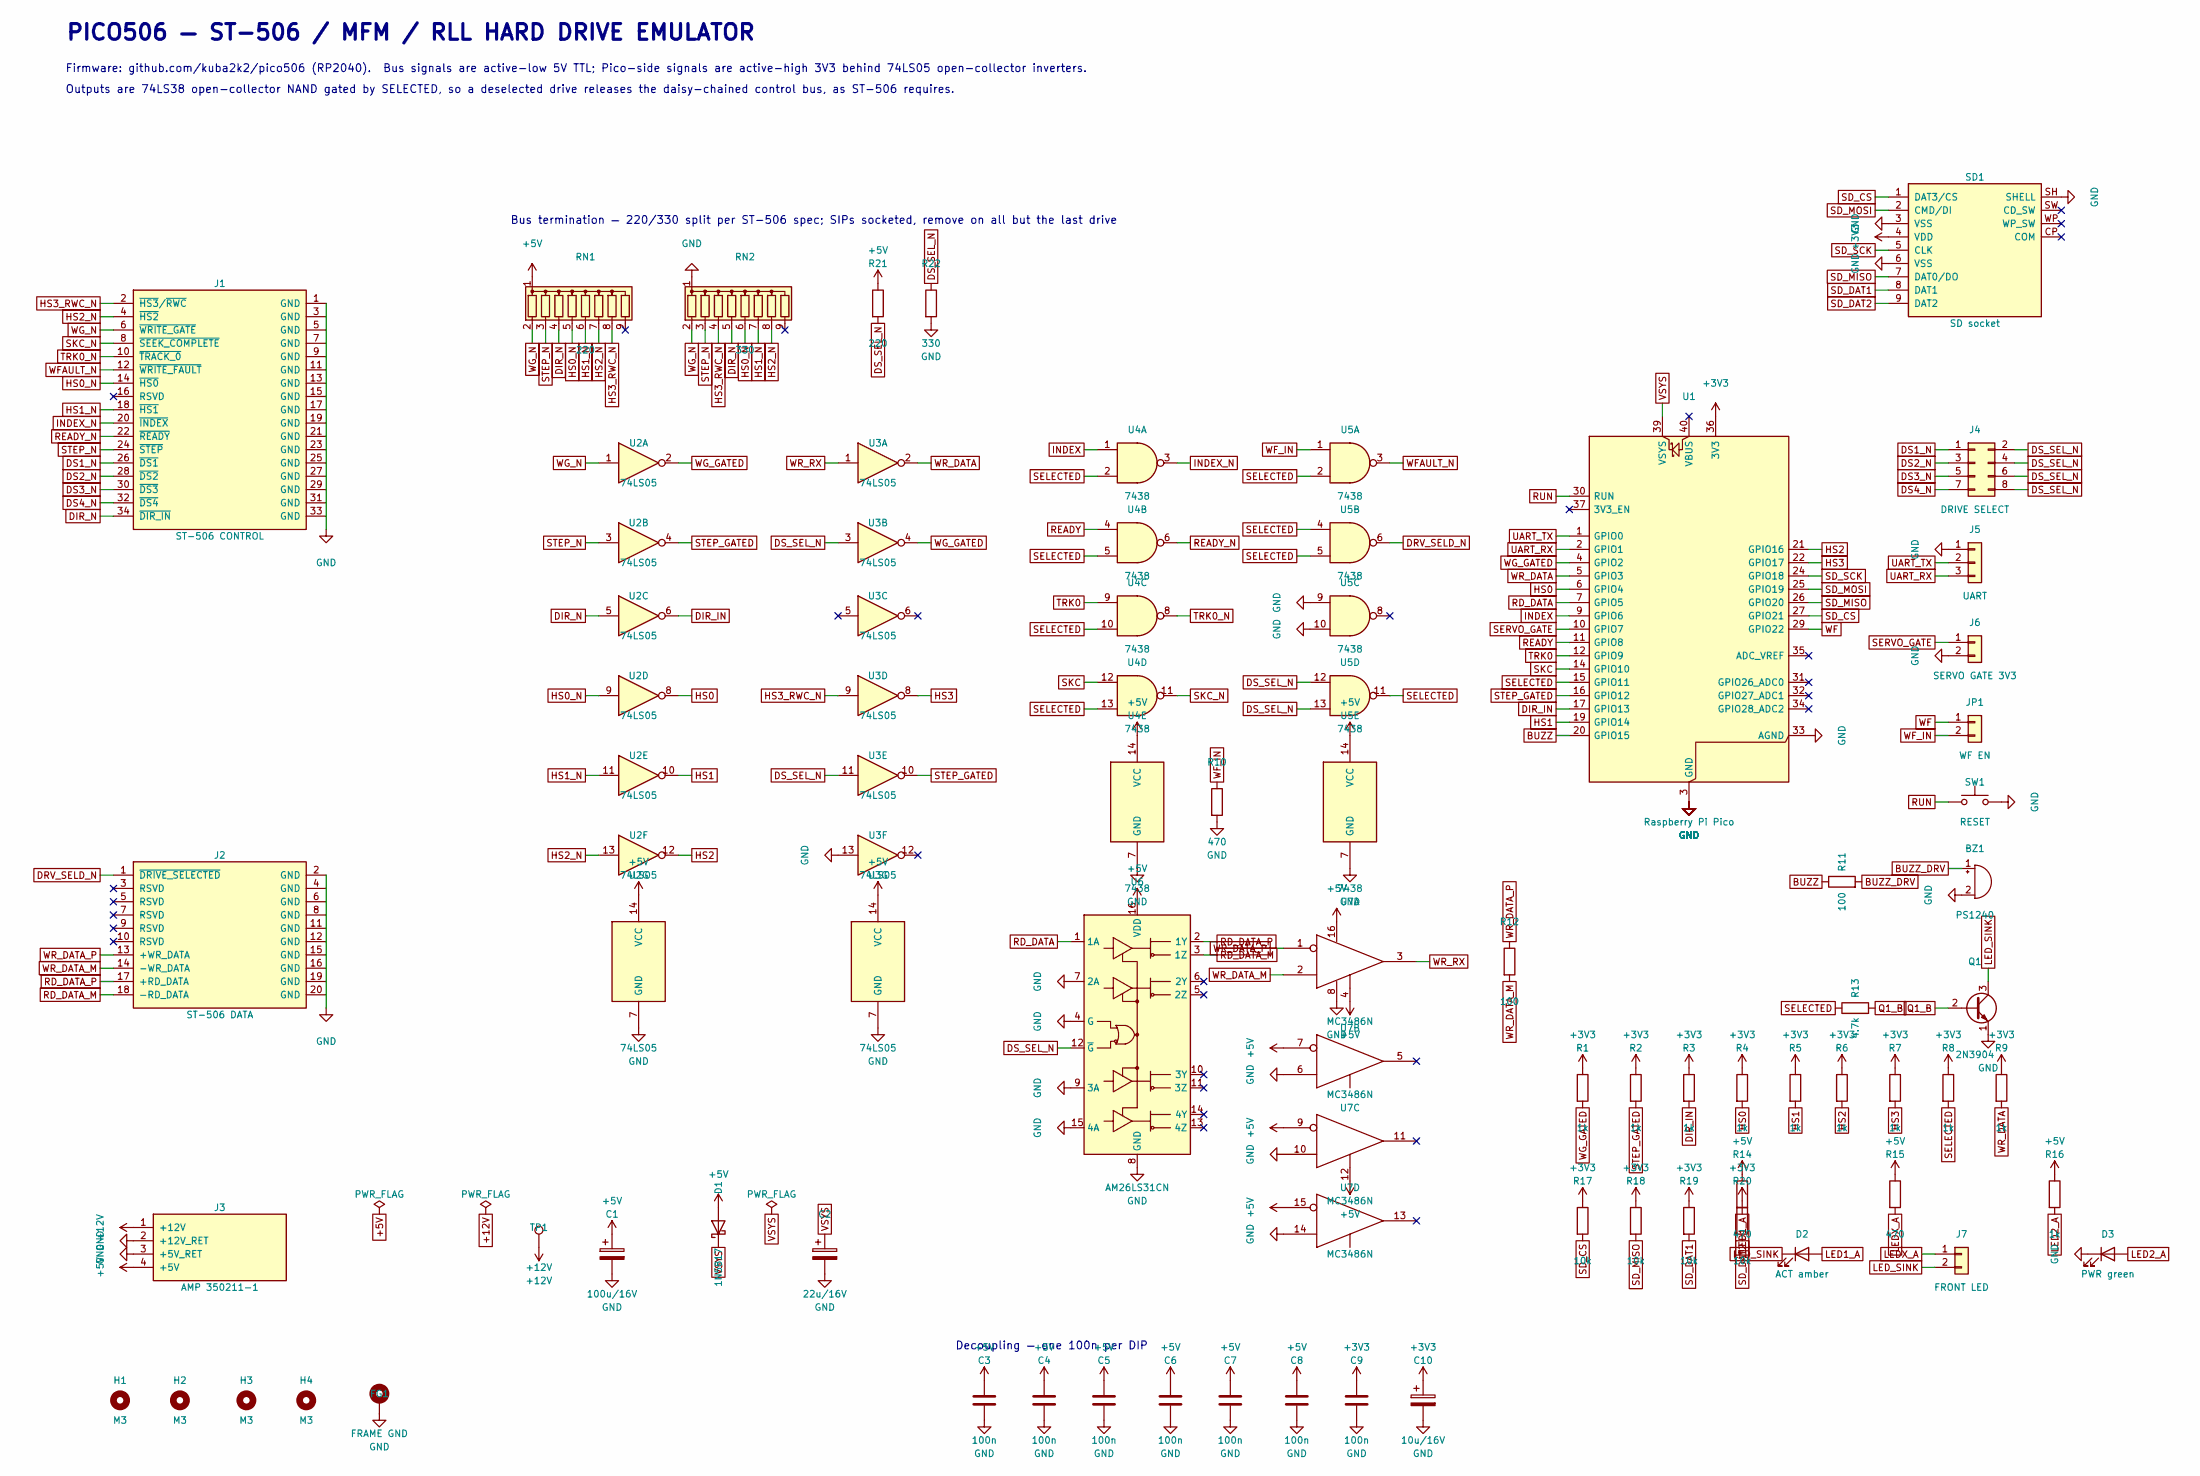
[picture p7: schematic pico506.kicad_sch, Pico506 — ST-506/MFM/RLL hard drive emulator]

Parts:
BZ1: PS1240; Buzzer_TDK_PS1240P02BT_D12.2mm_H6.5mm
C1: 100u/16V; CP_Radial_D6.3mm_P2.50mm
C2: 22u/16V; CP_Radial_D5.0mm_P2.50mm
C3, C4, C5, C6, C7, C8, C9: 100n; C_Disc_D5.0mm_W2.5mm_P5.00mm
C10: 10u/16V; CP_Radial_D5.0mm_P2.50mm
D1: 1N5817; D_DO-41_SOD81_P10.16mm_Horizontal
D2: ACT amber; LED_D5.0mm
D3: PWR green; LED_D5.0mm
FG1: FRAME GND; Faston_Tab_AMP61761
H1, H2, H3, H4: M3; MountingHole_3.2mm_M3
J1: ST-506 CONTROL; EdgeConn_ST506_J1_34
J2: ST-506 DATA; EdgeConn_ST506_J2_20
J3: AMP 350211-1; PWR_MATE-N-LOK_350211_Horizontal
J4: DRIVE SELECT; PinHeader_2x04_P2.54mm_Vertical
J5: UART; PinHeader_1x03_P2.54mm_Vertical
J6: SERVO GATE 3V3; PinHeader_1x02_P2.54mm_Vertical
J7: FRONT LED; PinHeader_1x02_P2.54mm_Vertical
JP1: WF EN; PinHeader_1x02_P2.54mm_Vertical
Q1: 2N3904; TO-92_Inline
R1, R2, R3, R4, R5, R6, R7, R8, R9, R16: 1k; R_Axial_DIN0207_L6.3mm_D2.5mm_P10.16mm_Horizontal
R10, R14, R15: 470; R_Axial_DIN0207_L6.3mm_D2.5mm_P10.16mm_Horizontal
R11, R12: 100; R_Axial_DIN0207_L6.3mm_D2.5mm_P10.16mm_Horizontal
R13: 4.7k; R_Axial_DIN0207_L6.3mm_D2.5mm_P10.16mm_Horizontal
R17, R18, R19, R20: 10k; R_Axial_DIN0207_L6.3mm_D2.5mm_P10.16mm_Horizontal
R21: 220; R_Axial_DIN0207_L6.3mm_D2.5mm_P10.16mm_Horizontal
R22: 330; R_Axial_DIN0207_L6.3mm_D2.5mm_P10.16mm_Horizontal
RN1: 220; R_Array_SIP9
RN2: 330; R_Array_SIP9
SD1: SD socket; SD_Hirose_DM1AA_SF_PEJ82
SW1: RESET; SW_PUSH_6mm_H4.3mm
TP1: +12V; TestPoint_Pad_D2.0mm
U1: Raspberry Pi Pico; RaspberryPi_Pico_Common_THT
U2, U3: 74LS05; DIP-14_W7.62mm
U4, U5: 7438; DIP-14_W7.62mm
U6: AM26LS31CN; DIP-16_W7.62mm
U7: MC3486N; DIP-16_W7.62mm

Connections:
+3V3: C9.1, C10.1, R1.1, R2.1, R3.1, R4.1, R5.1, R6.1, R7.1, R8.1, R9.1, R17.1, R18.1, R19.1, R20.1, SD1.4 (VDD), U1.36 (3V3)
+5V: C1.1, C3.1, C4.1, C5.1, C6.1, C7.1, C8.1, D1.2 (A), J3.4 (+5V), R14.1, R15.1, R16.1, R21.1, RN1.1 (common), U2.14 (VCC), U3.14 (VCC), U4.14 (VCC), U5.14 (VCC), U6.16 (VDD), U7.4 (ENABLE), U7.7 (E-), U7.9 (E-), U7.12 (ENABLE), U7.15 (E-), U7.16 (VCC)
+12V: J3.1 (+12V), TP1.1
BUZZ: R11.1, U1.20 (GPIO15)
BUZZ_DRV: BZ1.1 (+), R11.2
DIR_IN: R3.2, U1.17 (GPIO13), U2.6
DIR_N: J1.34 (~DIR_IN), RN1.4 (R3), RN2.5 (R4), U2.5
DRV_SELD_N: J2.1 (~DRIVE_SELECTED), U5.6
DS1_N: J1.26 (~DS1), J4.1
DS2_N: J1.28 (~DS2), J4.3
DS3_N: J1.30 (~DS3), J4.5
DS4_N: J1.32 (~DS4), J4.7
DS_SEL_N: J4.2, J4.4, J4.6, J4.8, R21.2, R22.1, U3.3, U3.11, U5.12, U5.13, U6.12 (~G)
GND: BZ1.2 (-), C1.2, C2.2, C3.2, C4.2, C5.2, C6.2, C7.2, C8.2, C9.2, C10.2, D3.1 (K), FG1.1, J1.1 (GND), J1.3 (GND), J1.5 (GND), J1.7 (GND), J1.9 (GND), J1.11 (GND), J1.13 (GND), J1.15 (GND), J1.17 (GND), J1.19 (GND), J1.21 (GND), J1.23 (GND), J1.25 (GND), J1.27 (GND), J1.29 (GND), J1.31 (GND), J1.33 (GND), J2.2 (GND), J2.4 (GND), J2.6 (GND), J2.8 (GND), J2.11 (GND), J2.12 (GND), J2.15 (GND), J2.16 (GND), J2.19 (GND), J2.20 (GND), J3.2 (+12V_RET), J3.3 (+5V_RET), J5.1, J6.2, Q1.1 (E), R10.2, R22.2, RN2.1 (common), SD1.3 (VSS), SD1.6 (VSS), SD1.SH (SHELL), SW1.2, U1.3 (GND), U1.8 (GND), U1.13 (GND), U1.18 (GND), U1.23 (GND), U1.28 (GND), U1.33 (AGND), U1.38 (GND), U2.7 (GND), U3.7 (GND), U3.13, U4.7 (GND), U5.7 (GND), U5.9, U5.10, U6.4 (G), U6.7 (2A), U6.8 (GND), U6.9 (3A), U6.15 (4A), U7.6 (E+), U7.8 (GND), U7.10 (E+), U7.14 (E+)
HS0: R4.2, U1.6 (GPIO4), U2.8
HS0_N: J1.14 (~HS0), RN1.5 (R4), RN2.6 (R5), U2.9
HS1: R5.2, U1.19 (GPIO14), U2.10
HS1_N: J1.18 (~HS1), RN1.6 (R5), RN2.7 (R6), U2.11
HS2: R6.2, U1.21 (GPIO16), U2.12
HS2_N: J1.4 (~HS2), RN1.7 (R6), RN2.8 (R7), U2.13
HS3: R7.2, U1.22 (GPIO17), U3.8
HS3_RWC_N: J1.2 (~HS3/~RWC), RN1.8 (R7), RN2.4 (R3), U3.9
INDEX: U1.9 (GPIO6), U4.1
INDEX_N: J1.20 (~INDEX), U4.3
LED1_A: D2.2 (A), R14.2
LED2_A: D3.2 (A), R16.2
LEDX_A: J7.1, R15.2
LED_SINK: D2.1 (K), J7.2, Q1.3 (C)
Q1_B: Q1.2 (B), R13.2
RD_DATA: U1.7 (GPIO5), U6.1 (1A)
RD_DATA_M: J2.18 (-RD_DATA), U6.3 (1Z)
RD_DATA_P: J2.17 (+RD_DATA), U6.2 (1Y)
READY: U1.11 (GPIO8), U4.4
READY_N: J1.22 (~READY), U4.6
RUN: SW1.1, U1.30 (RUN)
SD_CS: R17.2, SD1.1 (DAT3/CS), U1.27 (GPIO21)
SD_DAT1: R19.2, SD1.8 (DAT1)
SD_DAT2: R20.2, SD1.9 (DAT2)
SD_MISO: R18.2, SD1.7 (DAT0/DO), U1.26 (GPIO20)
SD_MOSI: SD1.2 (CMD/DI), U1.25 (GPIO19)
SD_SCK: SD1.5 (CLK), U1.24 (GPIO18)
SELECTED: R8.2, R13.1, U1.15 (GPIO11), U4.2, U4.5, U4.10, U4.13, U5.2, U5.4, U5.5, U5.11
SERVO_GATE: J6.1, U1.10 (GPIO7)
SKC: U1.14 (GPIO10), U4.12
SKC_N: J1.8 (~SEEK_COMPLETE), U4.11
STEP_GATED: R2.2, U1.16 (GPIO12), U2.4, U3.10
STEP_N: J1.24 (~STEP), RN1.3 (R2), RN2.3 (R2), U2.3
TRK0: U1.12 (GPIO9), U4.9
TRK0_N: J1.10 (~TRACK_0), U4.8
UART_RX: J5.3, U1.2 (GPIO1)
UART_TX: J5.2, U1.1 (GPIO0)
VSYS: C2.1, D1.1 (K), U1.39 (VSYS)
WF: JP1.1, U1.29 (GPIO22)
WFAULT_N: J1.12 (~WRITE_FAULT), U5.3
WF_IN: JP1.2, R10.1, U5.1
WG_GATED: R1.2, U1.4 (GPIO2), U2.2, U3.4
WG_N: J1.6 (~WRITE_GATE), RN1.2 (R1), RN2.2 (R1), U2.1
WR_DATA: R9.2, U1.5 (GPIO3), U3.2
WR_DATA_M: J2.14 (-WR_DATA), R12.2, U7.2 (E+)
WR_DATA_P: J2.13 (+WR_DATA), R12.1, U7.1 (E-)
WR_RX: U3.1, U7.3 (OUT)

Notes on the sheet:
PICO506 — ST-506 / MFM / RLL HARD DRIVE EMULATOR
Firmware: github.com/kuba2k2/pico506 (RP2040). Bus signals are active-low 5V TTL; Pico-side signals are active-high 3V3 behind 74LS05 open-collector inverters.
Outputs are 74LS38 open-collector NAND gated by SELECTED, so a deselected drive releases the daisy-chained control bus, as ST-506 requires.
Bus termination — 220/330 split per ST-506 spec; SIPs socketed, remove on all but the last drive
Decoupling — one 100n per DIP

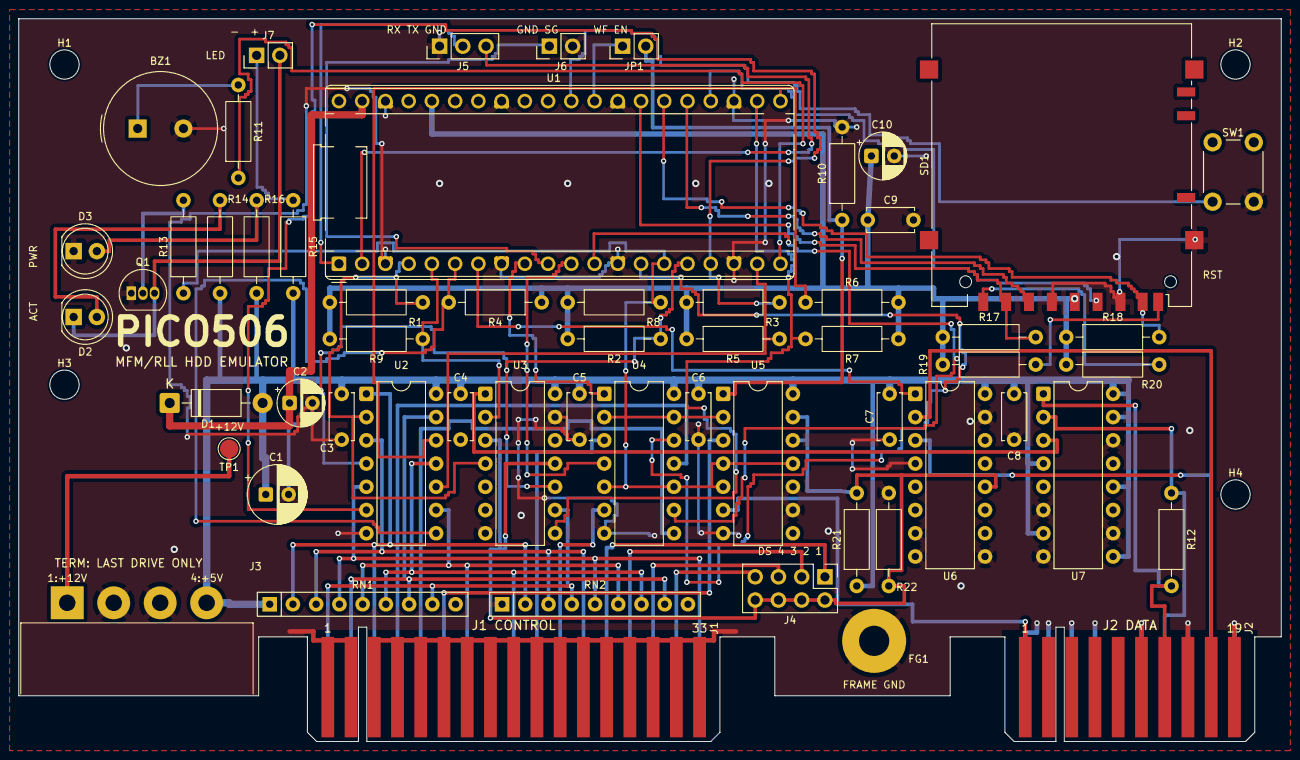
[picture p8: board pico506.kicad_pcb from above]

Board: 2 copper layers, 138.0 x 79.0 mm, 62 parts (0 on the bottom side), 61 nets.

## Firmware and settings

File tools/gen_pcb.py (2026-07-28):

#!/usr/bin/env python3
"""Generate pico506.kicad_pcb: outline with keyed card-edge tabs, placement,
routing, zones.  Consumes netlist.py + layout.py + the generated footprints."""

import json
import math
import os
import uuid as uuidlib

import layout as L
import netlist
import sexpr
from sexpr import q

HW = os.path.abspath(os.path.join(os.path.dirname(__file__), ".."))
KICAD_FP = "/Applications/KiCad/KiCad.app/Contents/SharedSupport/footprints"

OX, OY = L.ORIGIN_X, L.ORIGIN_Y

_uid_counter = 0


def uid():
    global _uid_counter
    _uid_counter += 1
    return str(uuidlib.uuid5(uuidlib.NAMESPACE_URL, f"pico506-pcb-{_uid_counter}"))


def fmt(v):
    s = f"{v:.4f}".rstrip("0").rstrip(".")
    return s if s not in ("-0", "") else "0"


def bx(x):
    return x + OX


def by(y):
    return y + OY


# ---------------------------------------------------------------------------
# nets
# ---------------------------------------------------------------------------

NETS = {"": 0}
for _n in sorted(netlist.nets()):
    NETS[_n] = len(NETS)


# ---------------------------------------------------------------------------
# placement (board-local coords, x east 0..138, y south 0..70, rear = y70)
# ---------------------------------------------------------------------------

PLACE = {
    # rear connector strip
    "J1": (L.J1_CENTER_X, L.BOARD_D, 0),
    "J2": (L.J2_CENTER_X, L.BOARD_D, 0),
    "J3": (L.J3_PIN1_X + 1.5 * L.J3_PITCH, L.BOARD_D - L.J3_ROW_SETBACK, 0),
    "FG1": (L.FG_X, L.BOARD_D - L.FG_Y_FROM_REAR, 0),

    # terminator + drive select row
    # SIP pads on the half-grid: every J1 finger escape passes exactly
    # between two SIP pads with 1.27 mm on each side
    "RN1": (27.43, 64.0, 0),
    "RN2": (52.83, 64.0, 0),
    "J4": (88.12, 61.0, 270),   # pin 1 east; columns DS4..DS1 west->east
    # +0.6 east of the natural 91.0/94.5: clears J4's courtyard to the west
    # and still leaves R22 clear of U6
    "R21": (91.6, 62.0, 90),
    "R22": (95.1, 62.0, 90),

    # DIP row (13 mm pitch leaves cap corridors between sockets)
    "U2": (38.0, 41.0, 0),
    "U3": (51.0, 41.0, 0),
    "U4": (64.0, 41.0, 0),
    "U5": (77.0, 41.0, 0),
    "U6": (98.0, 41.0, 0),
    "U7": (112.0, 41.0, 0),
    "R12": (126.0, 62.0, 90),

    # pull-up banks, horizontal; pin 2 (signal end) lands near its GPIO
    "R1": (34.0, 31.0, 0),      # WG_GATED   -> GP2
    "R9": (34.0, 35.0, 0),      # WR_DATA    -> GP3
    "R4": (57.16, 31.0, 180),   # HS0        -> GP4
    "R8": (60.0, 31.0, 0),      # SELECTED   -> GP11
    "R2": (60.0, 35.0, 0),      # STEP_GATED -> GP12
    "R3": (73.0, 31.0, 0),      # DIR_IN     -> GP13
    "R5": (73.0, 35.0, 0),      # HS1        -> GP14
    "R6": (96.16, 31.0, 180),   # HS2        -> GP16
    "R7": (96.16, 35.0, 180),   # HS3        -> GP17
    # SD pull-ups (pin 1 = 3V3 west)
    "R17": (101.0, 34.8, 0), "R18": (114.5, 34.8, 0),
    "R19": (101.0, 37.8, 0), "R20": (114.5, 37.8, 0),

    # Pico module (long axis E-W, USB west; origin = pin 1 at SW)
    "U1": (35.0, 26.78, 90),

    # power entry area (west)
    "C1": (27.0, 52.0, 0),
    "TP1": (23.0, 47.0, 0),
    "D1": (16.5, 42.0, 0),   # west, so C2 fits between it and C3
    "C2": (29.6, 42.0, 0),      # threads the gap between D1 and C3

    # front strip / indicators (west).  The LEDs, the TO-92 and the buzzer
    # were packed tight enough that their bodies actually fouled each other;
    # these positions give every pair a real gap (see tools/place_check.py).
    "BZ1": (13.0, 12.0, 0),
    "R11": (24.0, 17.4, 90),
    "Q1": (12.3, 30.0, 0),      # east of the LEDs: bodies overlapped at 10.0
    "R13": (18.0, 30.0, 90),
    "R14": (22.0, 30.0, 90),
    "R16": (26.0, 30.0, 90),
    "R15": (30.0, 30.0, 90),
    "D2": (6.0, 32.6, 0),       # spread 7.2 apart, not 6.0
    "D3": (6.0, 25.4, 0),
    "J7": (26.0, 4.0, 90),
    "SW1": (130.5, 20.0, 90),
    "J5": (46.0, 3.0, 90),
    "J6": (58.0, 3.0, 90),
    "JP1": (66.0, 3.0, 90),
    # R10 must stay at x90: the WF_IN riser threads between the +3V3 trunk
    # descent at x87.9 and R10's pad column, and 90.0 is what that fits
    "R10": (90.0, 22.0, 90),

    # SD socket, card exits the front (north) edge
    "SD1": (114.0, 16.0, 180),

    # decoupling (vertical in the inter-DIP corridors, +5V pad north)
    "C3": (35.3, 41.0, 270),   # U2
    "C4": (48.3, 41.0, 270),   # U3
    "C5": (61.3, 41.0, 270),   # U4
    "C6": (74.3, 41.0, 270),   # U5
    "C7": (95.2, 41.0, 270),   # U6
    "C8": (108.8, 41.0, 270),  # U7
    "C9": (92.8, 22.0, 0),     # SD 100n, east of R10's courtyard
    "C10": (93.2, 15.0, 0),    # SD 10u, east of R10's silk

    # mounting holes
    "H1": (5.0, 5.0, 0),
    "H2": (133.0, 5.0, 0),
    "H3": (5.0, 40.0, 0),
    "H4": (133.0, 52.0, 0),
}


# ---------------------------------------------------------------------------
# footprint loading / transformation
# ---------------------------------------------------------------------------

def fp_path(libid):
    lib, name = libid.split(":")
    if lib == "pico506-lib":
        return os.path.join(HW, "pico506-lib.pretty", f"{name}.kicad_mod")
    return os.path.join(KICAD_FP, f"{lib}.pretty", f"{name}.kicad_mod")


_fp_cache = {}


def load_fp(libid):
    if libid not in _fp_cache:
        with open(fp_path(libid)) as f:
            _fp_cache[libid] = sexpr.loads(f.read())
    return sexpr._deep_copy(_fp_cache[libid])


def pad_local(pad):
    at = sexpr.find(pad, "at")
    px, py = float(at[1]), float(at[2])
    pr = float(at[3]) if len(at) > 3 else 0.0
    return px, py, pr


def transform(px, py, X, Y, rot):
    th = math.radians(rot)
    gx = X + px * math.cos(th) + py * math.sin(th)
    gy = Y - px * math.sin(th) + py * math.cos(th)
    return gx, gy


PADS = {}      # (ref, pad) -> (gx, gy) board-local
PAD_INFO = {}  # (ref, pad) -> dict(layers=..., through=bool)

# collision model for the reference-designator placer, all board-local mm
PAD_BOXES = []    # (x0, y0, x1, y1) mask apertures — silk may not touch these
SILK_BOXES = []   # (ref, layer, x0, y0, x1, y1) footprint silk graphics
REF_NODES = {}    # ref -> (property node, X, Y, rot)

REF_SIZE = 0.8    # min_text_height is 0.8; smaller text fits more places
REF_THICK = 0.13


def text_box(s, x, y, size, rot, thick=0.0):
    """Conservative bbox of a stroke-font text centred at (x, y)."""
    w = len(s) * size * 0.85 + thick
    h = size * 1.15 + thick
    if rot % 180:
        w, h = h, w
    return (x - w / 2, y - h / 2, x + w / 2, y + h / 2)


def _custom_pad_reach(pad):
    """Farthest any custom-pad primitive gets from the pad's own origin."""
    prims = sexpr.find(pad, "primitives")
    if not prims:
        return 0.0
    best = 0.0
    for prim in prims[1:]:
        t = sexpr.tag(prim)
        if t == "gr_poly":
            for xy in sexpr.find_all(sexpr.find(prim, "pts"), "xy"):
                best = max(best, math.hypot(float(xy[1]), float(xy[2])))
        elif t == "gr_circle":
            c = sexpr.find(prim, "center")
            e = sexpr.find(prim, "end")
            cx, cy = float(c[1]), float(c[2])
            r = math.hypot(float(e[1]) - cx, float(e[2]) - cy)
            best = max(best, math.hypot(cx, cy) + r)
        else:
            for k in ("start", "mid", "end", "center"):
                n = sexpr.find(prim, k)
                if n:
                    best = max(best, math.hypot(float(n[1]), float(n[2])))
    return best


def _circumcircle(ps):
    """Centre and radius of the circle through three points, or None."""
    (ax, ay), (bx, by), (cx, cy) = ps
    d = 2 * (ax * (by - cy) + bx * (cy - ay) + cx * (ay - by))
    if abs(d) < 1e-9:
        return None
    a2, b2, c2 = ax * ax + ay * ay, bx * bx + by * by, cx * cx + cy * cy
    ux = (a2 * (by - cy) + b2 * (cy - ay) + c2 * (ay - by)) / d
    uy = (a2 * (cx - bx) + b2 * (ax - cx) + c2 * (bx - ax)) / d
    return (ux, uy), math.hypot(ax - ux, ay - uy)


def _shape_local_box(item):
    """Local bbox of a footprint graphic, or None if it isn't silk geometry."""
    t = sexpr.tag(item)
    pts = []
    if t in ("fp_line", "fp_rect"):
        for k in ("start", "end"):
            n = sexpr.find(item, k)
            pts.append((float(n[1]), float(n[2])))
    elif t == "fp_arc":
        # bound the whole circle the arc lies on: the endpoints alone
        # under-report a bulging arc, and under-reporting here lets a
        # reference designator land on top of it
        ps = []
        for k in ("start", "mid", "end"):
            n = sexpr.find(item, k)
            if n:
                ps.append((float(n[1]), float(n[2])))
        c = _circumcircle(ps) if len(ps) == 3 else None
        if c:
            (cx, cy), r = c
            pts = [(cx - r, cy - r), (cx + r, cy + r)]
        else:
            pts = ps
    elif t == "fp_circle":
        c = sexpr.find(item, "center")
        e = sexpr.find(item, "end")
        cx, cy = float(c[1]), float(c[2])
        r = math.hypot(float(e[1]) - cx, float(e[2]) - cy)
        pts = [(cx - r, cy - r), (cx + r, cy + r)]
    elif t == "fp_poly":
        for xy in sexpr.find_all(sexpr.find(item, "pts"), "xy"):
            pts.append((float(xy[1]), float(xy[2])))
    elif t == "fp_text":
        at = sexpr.find(item, "at")
        eff = sexpr.find(item, "effects")
        size = 1.0
        if eff:
            fnt = sexpr.find(eff, "font")
            sz = sexpr.find(fnt, "size") if fnt else None
            if sz:
                size = float(sz[1])
        s = sexpr.uq(item[2])
        b = text_box(s, float(at[1]), float(at[2]), size, 0)
        pts = [(b[0], b[1]), (b[2], b[3])]
    if not pts:
        return None
    return (min(p[0] for p in pts), min(p[1] for p in pts),
            max(p[0] for p in pts), max(p[1] for p in pts))


def _global_box(lx0, ly0, lx1, ly1, X, Y, rot):
    """Transform a local box's corners and re-bound them."""
    cs = [transform(x, y, X, Y, rot)
          for x, y in ((lx0, ly0), (lx1, ly0), (lx1, ly1), (lx0, ly1))]
    return (min(c[0] for c in cs), min(c[1] for c in cs),
            max(c[0] for c in cs), max(c[1] for c in cs))


def _overlaps(a, b, gap=0.0):
    return (a[0] < b[2] + gap and b[0] < a[2] + gap
            and a[1] < b[3] + gap and b[1] < a[3] + gap)


def place_footprint(ref, comp, sch_uuids):
    X, Y, rot = PLACE[ref]
    node = load_fp(comp["footprint"])
    node[0] = "footprint"
    node[1] = q(comp["footprint"])
    # strip any existing at/path/property Reference/Value; keep the rest
    keep = []
    for item in node[2:]:
        t = sexpr.tag(item)
        if t in ("at", "path", "property"):
            continue
        if t == "fp_text" and item[1] in ("reference", "value"):
            continue
        keep.append(item)
    body = node[:2]
    body.append(["layer", q("F.Cu")])
    body.append(["uuid", q(uid())])
    body.append(["at", fmt(bx(X)), fmt(by(Y)), fmt(rot)])
    if ref in sch_uuids:
        body.append(["path", q("/" + sch_uuids[ref])])
    ref_node = ["property", q("Reference"), q(ref),
                ["at", "0", "-2", "0"], ["layer", q("F.SilkS")],
                ["uuid", q(uid())],
                ["effects", ["font", ["size", fmt(REF_SIZE), fmt(REF_SIZE)],
                             ["thickness", fmt(REF_THICK)]]]]
    body.append(ref_node)
    REF_NODES[ref] = (ref_node, X, Y, rot)
    body.append(["property", q("Value"), q(comp["value"]),
                 ["at", "0", "2", fmt(rot)], ["layer", q("F.Fab")],
                 ["uuid", q(uid())],
                 ["effects", ["font", ["size", "0.9", "0.9"],
                              ["thickness", "0.14"]]]])
    anon = 0
    for item in keep:
        t = sexpr.tag(item)
        if t == "pad":
            pnum = sexpr.uq(item[1])
            net_key = pnum
            if not pnum or (ref, pnum) in PADS:
                anon += 1
                pnum = f"{net_key}~{anon}"
            px, py, pr = pad_local(item)
            gx, gy = transform(px, py, X, Y, rot)
            PADS[(ref, pnum)] = (gx, gy)
            layers_node = sexpr.find(item, "layers") or []
            size_node = sexpr.find(item, "size")
            psz = max(float(size_node[1]), float(size_node[2])) if size_node else 1.6
            if item[3] in ("rect", "roundrect"):
                psz *= 1.415
            elif item[3] == "custom":
                # (size) is only the anchor; the real copper is the primitives,
                # and the Pico's castellated pads reach well past it
                psz = max(psz, 2 * _custom_pad_reach(item))
            drill_node = sexpr.find(item, "drill")
            if drill_node:
                try:
                    psz = max(psz, float(drill_node[1]) + 0.2)
                except (TypeError, ValueError):
                    pass
            PAD_INFO[(ref, pnum)] = dict(
                through=item[2] in ("thru_hole", "np_thru_hole"),
                layers=[sexpr.uq(x) for x in layers_node[1:]],
                size=psz,
                net=comp["pins"].get(net_key),
            )
            # rewrite pad angle to include footprint rotation
            at = sexpr.find(item, "at")
            base = pr
            newang = (base + rot) % 360
            if len(at) > 3:
                at[3] = fmt(newang)
            elif newang:
                at.append(fmt(newang))
            # net assignment
            net = comp["pins"].get(pnum)
            item[:] = [x for x in item if sexpr.tag(x) not in ("net",)]
            if net:
                item.append(["net", str(NETS[net]), q(net)])
            # mask aperture, for the reference placer to keep silk off
            sx, sy = (float(size_node[1]), float(size_node[2])) if size_node \
                else (psz, psz)
            if (pr + rot) % 180:
                sx, sy = sy, sx
            PAD_BOXES.append((gx - sx / 2, gy - sy / 2, gx + sx / 2, gy + sy / 2))
        else:
            lb = _shape_local_box(item)
            lay = sexpr.find(item, "layer")
            if lb and lay and sexpr.uq(lay[1]) in ("F.SilkS", "B.SilkS"):
                SILK_BOXES.append((ref, sexpr.uq(lay[1]),
                                   *_global_box(*lb, X, Y, rot)))
        body.append(item)
    return body


def place_references():
    """Choose a spot for every reference designator.

    Every ref used to sit at a fixed local (0, -2), which buried a lot of them
    in pads and in their own footprint's silk.  Instead each one is offered
    positions around its part, working outwards, and takes the first that
    clears all mask apertures, all footprint silk, the board texts, the refs
    already placed, and the board edge.
    """
    own = {}
    for ref, layer, x0, y0, x1, y1 in SILK_BOXES:
        b = own.get(ref)
        own[ref] = (min(b[0], x0), min(b[1], y0), max(b[2], x1),
                    max(b[3], y1)) if b else (x0, y0, x1, y1)
    pads_of = {}
    for (ref, _pad), (gx, gy) in PADS.items():
        b = pads_of.get(ref)
        pads_of[ref] = (min(b[0], gx), min(b[1], gy), max(b[2], gx),
                        max(b[3], gy)) if b else (gx, gy, gx, gy)

    fixed = list(BOARD_TEXT_BOXES)
    placed = []
    unresolved = []
    # tightest parts first: they have the fewest options
    order = sorted(REF_NODES, key=lambda r: _extent_area(own.get(r) or pads_of.get(r)))
    for ref in order:
        node, X, Y, rot = REF_NODES[ref]
        hull = own.get(ref) or pads_of.get(ref) or (X, Y, X, Y)
        best = None
        for gx, gy, trot in _ref_candidates(hull, X, Y):
            box = text_box(ref, gx, gy, REF_SIZE, trot, REF_THICK)
            if not _ref_box_ok(box, ref):
                continue
            if any(_overlaps(box, o, 0.05) for o in fixed + placed):
                continue
            best = (gx, gy, trot, box)
            break
        if best is None:
            unresolved.append(ref)
            gx, gy = transform(0, -2, X, Y, rot)
            best = (gx, gy, 0, text_box(ref, gx, gy, REF_SIZE, 0, REF_THICK))
        gx, gy, trot, box = best
        placed.append(box)
        dx, dy = gx - X, gy - Y
        th = math.radians(rot)
        px = dx * math.cos(th) - dy * math.sin(th)
        py = dx * math.sin(th) + dy * math.cos(th)
        at = sexpr.find(node, "at")
        at[1], at[2], at[3] = fmt(px), fmt(py), fmt(trot)
    if unresolved:
        print("REF placer found no clear spot for:", " ".join(unresolved))


def _extent_area(b):
    return (b[2] - b[0]) * (b[3] - b[1]) if b else 0.0


def _ref_candidates(hull, X, Y):
    """Positions to try, nearest-and-tidiest first: centred above the part,
    then below, then the sides, then the corners, each at growing offsets."""
    x0, y0, x1, y1 = hull
    cx, cy = (x0 + x1) / 2, (y0 + y1) / 2
    h = REF_SIZE * 1.15 / 2 + 0.1
    for d in (0.25, 0.6, 1.1, 1.8, 2.6):
        yield (cx, y0 - h - d, 0)
        yield (cx, y1 + h + d, 0)
        yield (x1 + h + d, cy, 90)
        yield (x0 - h - d, cy, 90)
        yield (cx, y0 - h - d, 90)
        yield (cx, y1 + h + d, 90)
        for sx, sy in ((1, -1), (-1, -1), (1, 1), (-1, 1)):
            yield (cx + sx * ((x1 - x0) / 2 + d), cy + sy * ((y1 - y0) / 2 + h + d), 0)


def board_cutouts():
    """Rectangles inside the main outline where there is no board: the relief
    cut-outs beside each tab, and the part of each key slot that runs inboard
    of the rear edge.  The reference placer has to treat these as off-board."""
    D, T = L.BOARD_D, L.TAB_PROTRUDE
    ry = L.tab_relief_y()
    slot_top = D + T - L.KEY_SLOT_DEPTH
    sw = L.KEY_SLOT_W / 2
    out = []
    for cx, tw, ncols in ((L.J1_CENTER_X, L.J1_TAB_W, 17),
                          (L.J2_CENTER_X, L.J2_TAB_W, 10)):
        hw = tw / 2
        west, east = L.tab_relief_x(cx, tw)
        out.append((west, ry, cx - hw, D))
        out.append((cx + hw, ry, east, D))
        sx = L.key_slot_x(cx, ncols)
        out.append((sx - sw, slot_top, sx + sw, D))
    return out


CUTOUTS = board_cutouts()


def _ref_box_ok(box, ref):
    """Clear of every mask aperture, all footprint silk, and the board edge?"""
    if not (0.3 <= box[0] and box[2] <= L.BOARD_W - 0.3
            and 0.3 <= box[1] and box[3] <= L.BOARD_D - 0.3):
        return False
    for co in CUTOUTS:
        if _overlaps(box, co, 0.2):
            return False
    for pb in PAD_BOXES:
        if _overlaps(box, pb, 0.05):
            return False
    for _r, _layer, x0, y0, x1, y1 in SILK_BOXES:
        if _overlaps(box, (x0, y0, x1, y1), 0.05):
            return False
    return True


# ---------------------------------------------------------------------------
# board outline
# ---------------------------------------------------------------------------

def outline_nodes():
    W, D, T = L.BOARD_W, L.BOARD_D, L.TAB_PROTRUDE
    cc = L.TAB_CORNER
    ry = L.tab_relief_y()

    def tab_path(cx, tw, slot_x):
        """West-to-east rear-edge profile of one tab and its relief cut-outs.

        The tab's sides now run all the way from the relief's inboard edge
        (`ry`) out to the tip, so the tab is a free-standing tongue as long as
        the fingers rather than a 5 mm stub in a full-width edge.
        """
        hw = tw / 2
        sw = L.KEY_SLOT_W / 2
        sd = L.KEY_SLOT_DEPTH
        west, east = L.tab_relief_x(cx, tw)
        pts = []
        if west > 0.0:
            pts.append((west, D))
        pts += [(west, ry), (cx - hw, ry),
                (cx - hw, D + T - cc), (cx - hw + cc, D + T)]
        pts += [(slot_x - sw, D + T), (slot_x - sw, D + T - sd),
                (slot_x + sw, D + T - sd), (slot_x + sw, D + T)]
        pts += [(cx + hw - cc, D + T), (cx + hw, D + T - cc),
                (cx + hw, ry), (east, ry)]
        if east < W:
            pts.append((east, D))
        return pts

    rear = [(0.0, D)]
    for cx, tw, ncols in ((L.J1_CENTER_X, L.J1_TAB_W, 17),
                          (L.J2_CENTER_X, L.J2_TAB_W, 10)):
        rear += tab_path(cx, tw, L.key_slot_x(cx, ncols))
    if rear[-1][1] == D:
        rear.append((W, D))        # last relief stopped short of the east edge
    # north edge west-to-east, down the east edge, then the rear profile back
    path = [(0.0, 0.0), (W, 0.0)] + list(reversed(rear)) + [(0.0, 0.0)]

    nodes = []
    for (x1, y1), (x2, y2) in zip(path, path[1:]):
        if (x1, y1) == (x2, y2):
            continue
        nodes.append(["gr_line", ["start", fmt(bx(x1)), fmt(by(y1))],
                      ["end", fmt(bx(x2)), fmt(by(y2))],
                      ["stroke", ["width", "0.1"], ["type", "solid"]],
                      ["layer", q("Edge.Cuts")], ["uuid", q(uid())]])
    return nodes


# ---------------------------------------------------------------------------
# text / silk
# ---------------------------------------------------------------------------

def gr_text(s, x, y, layer, size=1.5, rot=0, bold=False, mirror=False):
    eff = ["effects", ["font", ["size", fmt(size), fmt(size)],
                       ["thickness", fmt(size * (0.2 if bold else 0.15))]]]
    if bold:
        eff[1].append(["bold", "yes"])
    if mirror:
        eff.append(["justify", "mirror"])
    return ["gr_text", q(s), ["at", fmt(bx(x)), fmt(by(y)), fmt(rot)],
            ["layer", q(layer)], ["uuid", q(uid())], eff]
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

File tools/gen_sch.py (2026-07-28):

#!/usr/bin/env python3
"""Generate pico506.kicad_sch from netlist.py + parts.py.

Connectivity style: every signal pin gets a global label at its tip; power
pins get power symbols (with stub wires when the pin exits sideways); unused
pins get no-connect markers.  Positions are all on the 1.27 mm grid.
"""

import uuid as uuidlib

import netlist
import parts
import sexpr
from sexpr import q

ROOT_UUID = "e5a1a1de-0000-4000-8000-000000000001"
PROJECT = "pico506"

POWER_NETS = {"GND": "power:GND", "+5V": "power:+5V",
              "+3V3": "power:+3V3", "+12V": "power:+12V"}

SYMS = parts.all_symbols()
BYREF = netlist.by_ref()

_uid_counter = 0


def uid():
    global _uid_counter
    _uid_counter += 1
    return str(uuidlib.uuid5(uuidlib.NAMESPACE_URL, f"pico506-sch-{_uid_counter}"))


def snap(v):
    return round(v / 1.27) * 1.27


def fmt(v):
    s = f"{v:.4f}".rstrip("0").rstrip(".")
    return s if s not in ("-0", "") else "0"


# ---------------------------------------------------------------------------
# symbol geometry
# ---------------------------------------------------------------------------

def unit_pins(libid, unit):
    """[(number, lx, ly, angle_deg)] for a unit (styles 0/1 + common unit 0)."""
    sym = SYMS[libid]
    base = sexpr.sym_name(sym).split(":", 1)[-1]
    # embedded parent name contains ':'; children are "<base>_u_s"
    out = []
    for child in sexpr.find_all(sym, "symbol"):
        cn = sexpr.sym_name(child)
        suffix = cn[len(base):] if cn.startswith(base) else cn.split("_", 1)[-1]
        parts_ = suffix.strip("_").split("_")
        if len(parts_) != 2:
            continue
        u, s = int(parts_[0]), int(parts_[1])
        if u not in (0, unit) or s == 2:
            continue
        for pin in sexpr.find_all(child, "pin"):
            at = sexpr.find(pin, "at")
            num = sexpr.uq(sexpr.find(pin, "number")[1])
            out.append((num, float(at[1]), float(at[2]), float(at[3])))
    return out


def n_units(libid):
    sym = SYMS[libid]
    base = sexpr.sym_name(sym).split(":", 1)[-1]
    units = set()
    for child in sexpr.find_all(sym, "symbol"):
        cn = sexpr.sym_name(child)
        if not cn.startswith(base):
            continue
        parts_ = cn[len(base):].strip("_").split("_")
        if len(parts_) == 2 and parts_[0].isdigit():
            u = int(parts_[0])
            if u > 0:
                units.add(u)
    return max(units) if units else 1


def xform(px, py, X, Y, rot):
    """Symbol-local (y-up) -> sheet (y-down) for rotation rot."""
    if rot == 0:
        return X + px, Y - py
    if rot == 90:
        return X - py, Y - px
    if rot == 180:
        return X - px, Y + py
    if rot == 270:
        return X + py, Y + px
    raise ValueError(rot)


def pin_dir(angle, rot):
    """Outward direction of a pin on the sheet, as 0/90/180/270 (sheet deg,
    0=right, 90=up, 180=left, 270=down)."""
    # local outward direction is angle+180 in y-up space
    out_up = (angle + 180.0) % 360
    # apply rotation (still y-up sense), then convert to sheet sense (same
    # names: right/up/left/down), because we only report cardinal names.
    total = (out_up + rot) % 360
    return int(total)


# ---------------------------------------------------------------------------
# emitters
# ---------------------------------------------------------------------------

SCH = []   # accumulated top-level nodes


SYM_UUIDS = {}   # ref -> unit-1 instance uuid (for PCB footprint linkage)


def emit_symbol_instance(ref, libid, unit, X, Y, rot, value, footprint,
                         extra_fields=None, dnp=False, value_hide=False):
    pins = unit_pins(libid, unit)
    iu = uid()
    if unit == 1:
        SYM_UUIDS[ref] = iu
    node = ["symbol", ["lib_id", q(libid)],
            ["at", fmt(X), fmt(Y), str(rot)],
            ["unit", str(unit)],
            ["exclude_from_sim", "no"], ["in_bom", "yes"],
            ["on_board", "yes"], ["dnp", "yes" if dnp else "no"],
            ["uuid", q(iu)]]
    ys = [xform(px, py, X, Y, rot)[1] for _, px, py, _ in pins] or [Y]
    topy, boty = min(ys) - 2.54, max(ys) + 2.54
    node.append(["property", q("Reference"), q(ref),
                 ["at", fmt(X), fmt(topy - 1.27), "0"], _ef()])
    node.append(["property", q("Value"), q(value),
                 ["at", fmt(X), fmt(boty + 1.27), "0"], _ef(hide=value_hide)])
    node.append(["property", q("Footprint"), q(footprint),
                 ["at", fmt(X), fmt(boty + 3.81), "0"], _ef(hide=True)])
    node.append(["property", q("Datasheet"), q(""),
                 ["at", fmt(X), fmt(boty + 6.35), "0"], _ef(hide=True)])
    for fname, fval in (extra_fields or {}).items():
        node.append(["property", q(fname), q(fval),
                     ["at", fmt(X), fmt(boty + 8.89), "0"], _ef(hide=True)])
    for num, _, _, _ in sorted(pins, key=lambda p: p[0]):
        node.append(["pin", q(num), ["uuid", q(uid())]])
    node.append(["instances",
                 ["project", q(PROJECT),
                  ["path", q("/" + ROOT_UUID),
                   ["reference", q(ref)], ["unit", str(unit)]]]])
    SCH.append(node)
    return pins


def _ef(hide=False, justify=None):
    e = ["effects", ["font", ["size", "1.27", "1.27"]]]
    if justify:
        e.append(["justify", justify])
    if hide:
        e.append(["hide", "yes"])
    return e


def emit_glabel(net, x, y, direction):
    rot = {0: "0", 90: "90", 180: "180", 270: "270"}[direction]
    justify = "left" if direction in (0, 90) else "right"
    SCH.append(["global_label", q(net), ["shape", "passive"],
                ["at", fmt(x), fmt(y), rot],
                _ef(justify=justify),
                ["uuid", q(uid())],
                ["property", q("Intersheetrefs"), q("${INTERSHEET_REFS}"),
                 ["at", fmt(x), fmt(y), "0"], _ef(hide=True)]])


def emit_wire(x1, y1, x2, y2):
    SCH.append(["wire", ["pts", ["xy", fmt(x1), fmt(y1)],
                         ["xy", fmt(x2), fmt(y2)]],
                ["stroke", ["width", "0"], ["type", "default"]],
                ["uuid", q(uid())]])


def emit_nc(x, y):
    SCH.append(["no_connect", ["at", fmt(x), fmt(y)], ["uuid", q(uid())]])


def emit_junction(x, y):
    SCH.append(["junction", ["at", fmt(x), fmt(y)], ["diameter", "0"],
                ["color", "0", "0", "0", "0"], ["uuid", q(uid())]])


def emit_text(s, x, y, size=2.0, bold=False):
    e = ["effects", ["font", ["size", fmt(size), fmt(size)]]]
    if bold:
        e[1].append(["bold", "yes"])
    e.append(["justify", "left", "bottom"])
    SCH.append(["text", q(s), ["exclude_from_sim", "no"],
                ["at", fmt(x), fmt(y), "0"], e, ["uuid", q(uid())]])


_power_seq = 0
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

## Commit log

2026-07-28 Add Pico506 PCB: rev 1.0, DRC and ERC clean
    [pico506-bom.csv, pico506.kicad_pcb, pico506.kicad_sch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]
2026-07-28 Point silkscreen at this repo, credit upstream firmware
    [pico506.kicad_pcb, pico506.kicad_sch]

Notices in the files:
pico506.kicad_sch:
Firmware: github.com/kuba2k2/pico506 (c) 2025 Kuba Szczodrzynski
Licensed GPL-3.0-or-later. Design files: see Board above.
